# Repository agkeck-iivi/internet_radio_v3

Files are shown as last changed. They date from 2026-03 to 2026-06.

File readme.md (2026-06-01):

# Internet radio v3

# this archive is now historical.  Active development is moved to https://codeberg.org/agkeck/internet_radio_v3

## hardware

* ESP32s3 DevkitC N8R8
* [adafruit pcm5122 audio board](https://learn.adafruit.com/adafruit-pcm5122-i2s-dac/)
*

### prototype

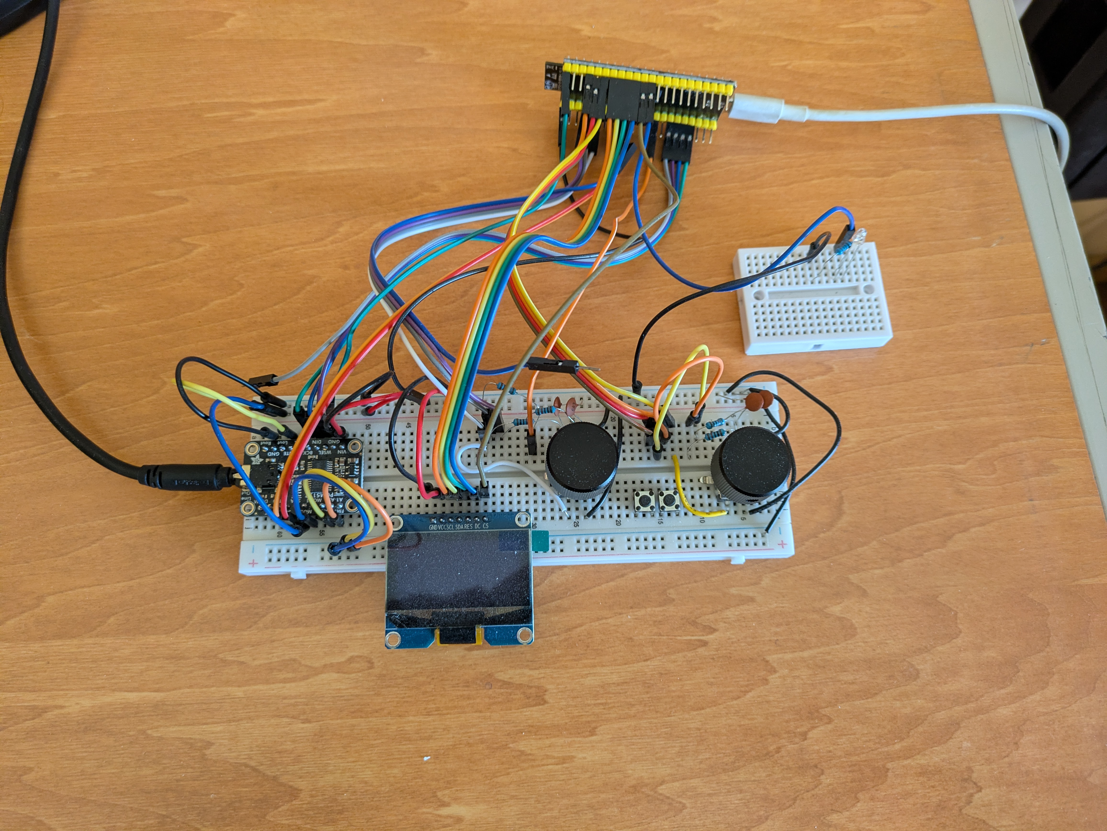
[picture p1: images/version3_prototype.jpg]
Version 3 Prototype


### schematic

Version 3 Schematic

### build

**Version 1**
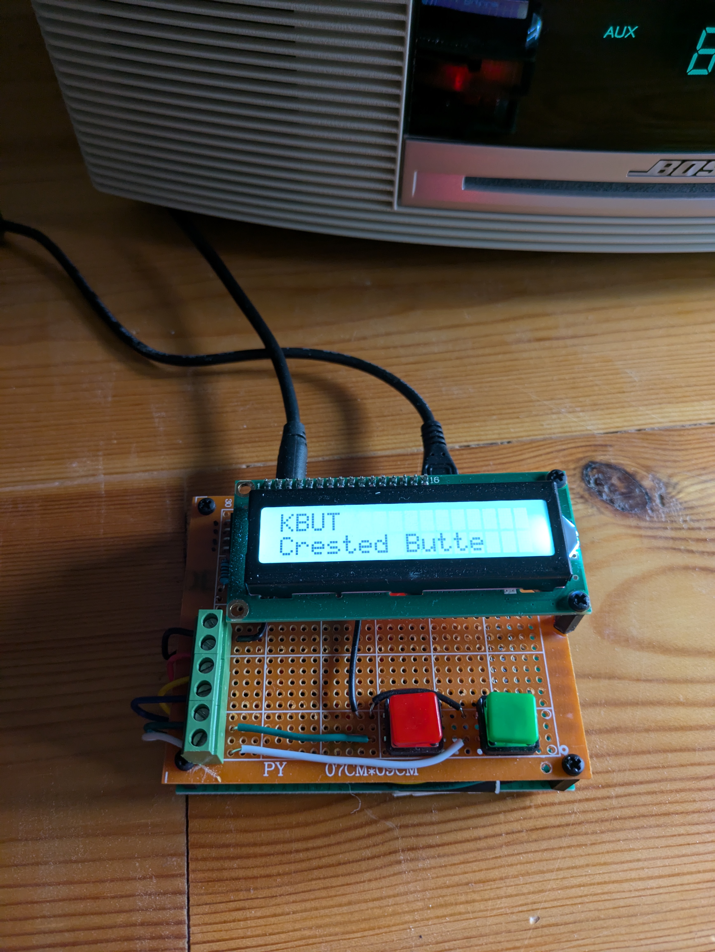
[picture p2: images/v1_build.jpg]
Version 1 Build


**Version 2**
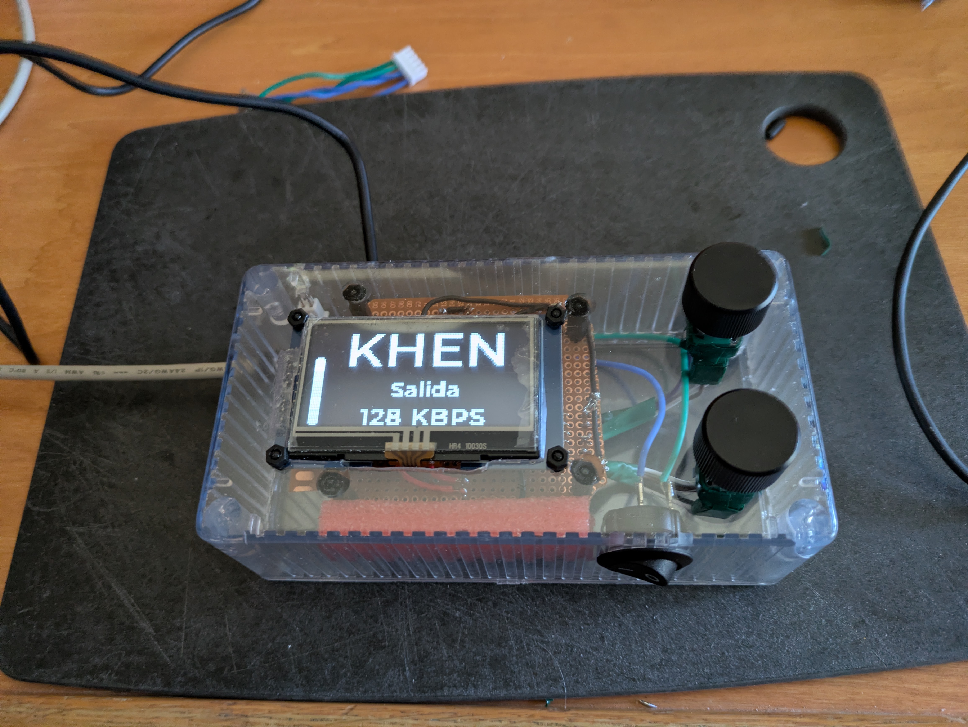
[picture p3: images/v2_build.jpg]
Version 2 Build


**Version 3**
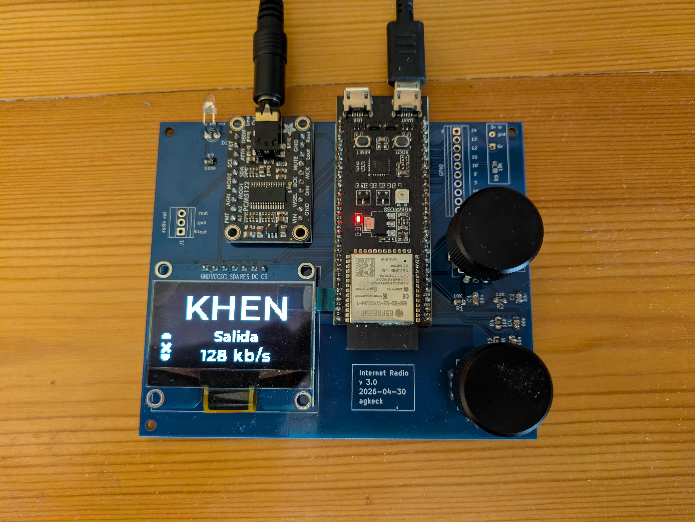
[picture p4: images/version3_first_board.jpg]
Version 3 Build


## software

### version 3 software highlights

Version 3 represents a significant refinement in performance, power management, and hardware integration. Key changes include:

* **Audio Hardware Migration**: Moved from the ES8388 codec to the high-performance **PCM5122 DAC**. This included implementing logarithmic volume scaling for a natural listening experience and custom digital ramp rates for glitch-free transitions.
* **Boot Speed Optimization (Fast Connect)**: Cold boot time was reduced from ~21 seconds to **~6 seconds** by implementing WiFi state persistence in NVS. The system now caches BSSID, channel, IP, and DNS settings to bypass discovery and DHCP phases.
* **Advanced Power Management**: Introduced a configurable power-saving strategy supporting **Light Sleep** and **Deep Sleep** transitions. This includes robust watchdog protection to prevent system hangs during sleep-state changes.
* **Dedicated IR Component**: Extracted Bose IR protocol logic into a reusable `ir_remote` component. The system now automatically synchronizes external audio power states during the device's boot and sleep cycles.
* **UI & Observability**: Refined the LVGL interface with a queue-based thread-safety pattern, real-time throughput tracking (kb/s), and custom graphical indicators (e.g., specialized mute glyphs).
* **Web Configuration**: Introduced a web interface for managing device settings (Analog/Digital attenuation, Power Save modes) with immediate runtime application.
* **NVS Configuration Persistence**: All application settings are now persisted to NVS using individual keys, ensuring backward compatibility and state retention across reboots.
* **Stability & Cleanup**: Factored all hardware assignments into a central GPIO header, implemented spurious encoder signal blanking on wakeup, and aligned the project with **ESP-IDF v5.4.3**.

### audio pipeline

The audio pipeline is virtually the same as in version 1.  We added an accumulator to count the bytes read from the http stream and a periodic task to calculate/update the bitrate display on the screen.  This task calculates a 10 second weighted average of one second bitrates.  When this weighted average is 0 we know that we have not received data for 10 seconds.  We use this signal along with a delay of 15 seconds to determine if we need to reboot the device.  If we have not received data for 10 seconds and we are at least 15 seconds since last boot we reboot the device.

### audio board

In Version 3, the radio migrated from the ES8388 (legacy LyraT design) to the high-performance **PCM5122 DAC** (Adafruit board).

The PCM5122 integration features:

* **Custom Driver**: A dedicated driver implementation that adheres to ESP-ADF conventions while providing low-level register control.
* **Analog Gain Control**: To manage the high output levels of the PCM5122, we implemented a 6 dB reduction in the analog gain stage (Page 1, Register 2).
* **Logarithmic Volume Scaling**: Volume settings (0-100) are mapped logarithmically to the DAC's digital volume registers to provide a natural, linear-sounding response to the user.
* **Attenuation Considerations**: Despite the 6 dB analog reduction, the output remains quite loud. Further digital or analog attenuation may be required in future revisions to better align the volume range with typical AUX-input sensitivities.

### encoders

The hardware pulse counters track the position of the encoders. This device has interupts for pulse thresholds but not for changes in pulse counts.  We use a polling task to check the pulse counts and update the encoder position.  For the volume encoder we clamp the value to the range [0, 100] and arrange the relationship between the pulse count and the [0, 100] range to saturate at the endpoints.  In this way, even if the user turns well past an endpoint the reverse movement will immediately affect the value.

### lvgl

LVGL is used for the display interface. Since LVGL is not thread-safe, we implement a **Queue-based Producer/Consumer pattern** to manage all UI updates safely.

#### Thread Safety & Queue

* **Producer**: Any task (e.g., Wi-Fi events, Encoder Logic) that wants to update the UI creates a `ui_update_message_t` struct. This struct contains an event `type` (enum) and optional `data` (int or string pointer). This message is sent to `g_ui_queue`.
* **Consumer**: The `process_ui_updates()` function runs in the main loop (or a dedicated UI task). It consumes messages from `g_ui_queue` and performs the actual LVGL API calls (e.g., `lv_label_set_text`, `lv_screen_load`). This ensures all LVGL operations happen in a single context.

#### Screens

The application uses three primary screens:

1. **Home Screen**: The main dashboard showing the Volume Slider, Station Call Sign, Origin, and Bitrate.
2. **Station Selection**: Displays a "Roller" widget allowing the user to scroll through the list of stations.
3. **Message Screen**: A generic, reusable screen with a centered label used for notifications (e.g., "Rebooting", "Provisioning", "IP Address").

#### Messaging

To display a message on the **Message Screen**:

1. **Fixed Messages**: Helper functions like `switch_to_reboot_screen()` send a message type (e.g., `SWITCH_TO_REBOOT_SCREEN`) that triggers the consumer to load the Message Screen and set a hardcoded string (e.g., "Rebooting").
2. **Arbitrary Messages**: To display dynamic text (like an IP address), the system uses the `UPDATE_IP_LABEL` message type.
    * The producer sends a message with `type = UPDATE_IP_LABEL` and `data.str_value = "My String"`.
    * The consumer reads specific string pointer and updates the label on the Message Screen.
    * *Note: Ensure the string pointer remains valid until processed, or use static/global buffers.*

### wifi

The device relies on Wi-Fi for internet connectivity. If no Wi-Fi credentials are provided (e.g., typically on the first boot), the device enters **Provisioning Mode**.

**Provisioning Mode**:

* The device broadcasts a Bluetooth LE (BLE) service.
* Use the **Espressif BLE Provisioning** app (available on iOS and Android) to connect to the device.
* Follow the app instructions to scan for Wi-Fi networks and provide the SSID and password.
* Once credentials are received, the device will connect to the Wi-Fi network and save the credentials to NVS for future boots.
* **Forced Reprovisioning**: To reset the Wi-Fi credentials and force the device back into provisioning mode, **press and hold the Volume Encoder button** while powering on (or rebooting) the device.

### ir

The Bose Wave radio uses an IR remote control for all functions. Version 2 is designed for this particular unit so we generate our own IR signals to control the radio.  After sniffing the IR signals with ir_nec_transciever project we see that the radio does not use the NEC protocal.  Using 10 samples of the on/off button and 10 samples of the aux button we create a concensus signal for each message. The colab: `bose_sig_analysis.ipynb` shows the analysis of the IR signals.

The bose IR protocal is stateful: the on/off button performs different functions based on the state of the radio.  The aux button is stateless, this signal will always result in the radio being on with input from the aux jack.  Therefore we use aux as the on signal and aux + on/off as the off signal.  We send aux during the boot sequence to ensure that the radio is on when we boot.  We expect the user to double click the volume encoder to turn the radio off.

### nvs

The system uses Non-Volatile Storage (NVS) to persist all critical states and settings:

* **Application Settings**: Analog and Digital attenuation, Power Save mode, sleep delays, and IR transmitter status.
* **Device State**: Current volume level, mute status, and the last selected station index.
* **WiFi State**: Cached BSSID, channel, and IP configuration for "Fast Connect" boot optimizations.

Settings are stored under the `app_config` namespace using individual keys for robust schema evolution.

### application configuration

The radio provides a web interface and a JSON API for real-time configuration. Access the interface at `http://<ESP32_IP_ADDRESS>/config`.

#### Configuration Parameters

| Parameter | Key | Values | Description |
| :--- | :--- | :--- | :--- |
| **Analog Attenuation** | `analog_attenuation` | `0` (0dB), `1` (-6dB) | Hardware gain stage control. |
| **Digital Attenuation** | `digital_attenuation` | `0, 6, 12, ..., 48` | Digital signal scaling after hardware gain. |
| **Power Save Mode** | `power_save_mode` | `0` (None), `1` (Light), `2` (Deep) | Sleep strategy selection. |
| **Light Sleep Delay** | `light_sleep_delay_ms` | Milliseconds | Timeout to enter Light Sleep. |
| **Deep Sleep Delay** | `deep_sleep_delay_ms` | Milliseconds | Additional timeout to move from Light to Deep Sleep. |
| **IR Remote Control** | `ir_protocol` | `0` (None), `1` (Bose Wave), `2` (Dubas Radio) | IR remote protocol selection. |

#### API Access

* **GET `/api/config`**: Returns the current application configuration.
* **POST `/api/config`**: Updates the configuration immediately. Changes are persisted to NVS.

Example update with all parameters:

```bash
curl -X POST -H "Content-Type: application/json" \
     -d '{
       "analog_attenuation": 1,
       "digital_attenuation": 12,
       "power_save_mode": 2,
       "light_sleep_delay_ms": 30000,
       "deep_sleep_delay_ms": 60000,
       "ir_protocol": 1
     }' \
     http://<ESP32_IP_ADDRESS>/api/config
```

Initial station data is stored in a constant array.  On first boot, if the spiffs is not initialized we create a default station json file based on the constant array.  Thereafter, on boot the spiffs should be found and the json file serves as the source of truth for station data.  We provide an API to load the station data from the json file and save the station data to the json file.

To download the current stations:

```bash
curl http://<ESP32_IP_ADDRESS>/api/stations -o stations.json
```

To update the stations:

```bash
curl -X POST -H "Content-Type: application/json" -d @stations.json http://<ESP32_IP_ADDRESS>/api/stations
```

where the codec enum uses these values:

0: MP3
1: AAC
2: OGG
3: FLAC

For help finding stream URIs and codecs for your favorite stations, see the [Station Discovery Guide](station_discovery.md).

### web update to station data

We provide a web interface to update the station data at <ESP32_IP_ADDRESS>/api/stations (or just <ESP_IP_ADDRESS> where there is a link to station data.)  From the web interface we can add, remove, and update station data as well a reorder the list of stations.  The station data is saved to the spiffs and a reboot will apply the changes.

## power management

The radio implements a multi-stage power-saving strategy to minimize energy consumption when idle.

*Note: In local tests setting the router's default dns server to 8.8.8.8  (google dns) or 1.1.1.1 (cloudflare dns) results in faster wakeup times.*

### Power Requirements Table

The following table outlines the current draw and estimated annual energy costs for each operational state. Estimates assume 24/7 operation in the specified state and an electricity cost of **$0.15 per kWh**.

| State | Current (mA) | Power (W) | Annual Energy (kWh) | Annual Cost ($)* |
| :--- | :--- | :--- | :--- | :--- |
| **None (Active)** | 190 | 0.95 | 8.32 | $1.25 |
| **Light Sleep** | 18 | 0.09 | 0.79 | $0.12 |
| **Deep Sleep** | ~8 (est.)† | 0.04 | 0.35 | $0.05 |

*\*Costs are rounded to the nearest cent.*
*†Deep sleep current is dominated by the DevKitC's onboard LDO quiescent current (~5mA) and Power LED (~3mA), as the ESP32-S3 chip itself draws <100µA in this state.*

#### Sleep States

* **Light Sleep**: Entered after a period of inactivity while muted. The CPU state is preserved, and the **SSD1306 screen is automatically powered off** to save energy. The system can be woken by either encoder button.
* **Deep Sleep**: Entered after an extended period in light sleep (if configured). The system performs a full power-down. **Only the Station button (GPIO 6)** can wake the device from this state.
* **IR Sync**: If enabled, the system automatically sends a "Power Off" IR command to the Bose radio when entering sleep, and a "Power On" command when waking.

## operation

The radio's user interface is driven by two rotary encoders, each equipped with an integrated push button (switch).

### Control Summary Table

| Control | Action | Function |
| :--- | :--- | :--- |
| **Volume Encoder** | Rotation | Adjust volume (0-100); Auto-unmutes if turned |
| | Single Click | Toggle Mute/Unmute; **Wake from Light Sleep** |
| | Double Click | Send **Bose ON/OFF** IR command |
| | **Hold at Boot** | **Force Reprovisioning** (Wipe Wi-Fi credentials) |
| **Station Encoder** | Rotation | Scroll through stations; Selects after 2s inactivity |
| | Short Press | Display **IP Address** (3s); **Wake from Mute/Sleep** |
| | Long Press (>1.5s) | **Reboot** device |

---

### Detailed Usage

#### Volume Encoder (Left)

* **Rotation**: Sets the volume level between 0 and 100.
  * The volume is saved to NVS and persists across reboots.
  * If the device is muted, any rotation will automatically restore the previous volume plus or minus the rotation delta.
* **Single Click**: Toggles the mute state.
  * **Wakeup**: If the device is in **Light Sleep**, clicking this button will wake the system and automatically unmute the audio.
* **Double Click**: Triggers the IR transmitter to send a power toggle command to the connected Bose system.
* **Boot Action**: Holding this button during power-on or reset will trigger `wifi_prov_mgr_reset_provisioning()`, allowing you to connect a new Wi-Fi network via BLE.

#### Station Encoder (Right)

* **Rotation**: Navigates the station list.
  * Turning the knob switches the display to the **Station Selection** screen.
  * **Auto-Selection**: Once you stop turning, the radio waits for **2 seconds** before committing the change, switching the stream, and returning to the Home screen.
* **Short Press**:
  * **Normal Mode**: Briefly switches the screen to show the current IP address.
  * **Mute/Sleep Mode**: If the device is muted or in **Light Sleep**, this button acts as a "Wake" key, restoring the audio immediately.
  * **Deep Sleep Wakeup**: This is the **primary wakeup button** for Deep Sleep. Because GPIO 6 is an RTC-capable pin, it is used to bring the system back from a deep sleep state (performing a full reboot).
* **Long Press**: Holding for more than 1.5 seconds triggers an immediate system reboot.

## Bugs

* Between the prototype and the first board we moved the volume button to gpio 42 to facilitate traces on the PCB.  Unfortunately we forgot that gpio 42 is not an RTC GPIO pin.  As a result, the volume button cannot wake the device from deep sleep.  We moved the wakeup function to the station button (gpio 6) and that works fine.  Currently volume turns it off and station turns it on.  We'll see how that works for us.

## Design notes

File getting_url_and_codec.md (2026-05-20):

# How to find url/codec for  radio streams, current song, and bitrate

## Identifying url

<https://fmstream.org> or ask gemini

## Identifying codec

```{bash}
ffprobe -v error -select_streams a:0 -show_entries stream=codec_name -of default=noprint_wrappers=1:nokey=1 <url>
```

## Measuring bitrate

```{bash}
ffprobe -v error -select_streams a:0 -show_entries stream=bit_rate -of default=noprint_wrappers=1:nokey=1 <url>
```

## getting currently playing song

### kexp

```{bash}
curl -s "https://api.kexp.org/v2/plays/?limit=1" | jq '.results[0] | {artist, song, album}'
```

## Station Bitrate Reference

The following table shows the measured bitrates for the default radio stations (calculated using `ffprobe`).

| Call Sign | Measured Bitrate | Sampling Frequency | URI |
| :--- | :--- | :--- | :--- |
| KEXP | 160 kbps | 44100 Hz | `https://kexp.streamguys1.com/kexp160.aac` |
| KBUT | 64 kbps | 22050 Hz | `http://playerservices.streamtheworld.com/api/livestream-redirect/KBUTFM.mp3` |
| KSUT | 64 kbps | 48000 Hz | `https://ksut.streamguys1.com/kute` |
| KDUR | 128 kbps | 44100 Hz | `https://kdurradio.fortlewis.edu/stream` |
| KOTO | 128 kbps | 44100 Hz | `http://playerservices.streamtheworld.com/api/livestream-redirect/KOTOFM.mp3` |
| KHEN | 128 kbps | 44100 Hz | `https://stream.pacificaservice.org:9000/khen_128` |
| KWSB | 128 kbps | 44100 Hz | `https://kwsb.streamguys1.com/live` |
| KFFP | 256 kbps | 44100 Hz | `http://listen.freeformportland.org:8000/stream` |
| KBOO | 192 kbps | 48000 Hz | `https://live.kboo.fm:8443/high` |
| KXLU | 48 kbps | 44100 Hz | `http://kxlu.streamguys1.com:80/kxlu-lo` |
| WPRB | 96 kbps | 44100 Hz | `https://wprb.streamguys1.com/listen.mp3` |
| WMBR | 128 kbps | 44100 Hz | `https://wmbr.org:8002/hi` |
| KALX | 128 kbps | 48000 Hz | `https://stream.kalx.berkeley.edu:8443/kalx-128.mp3` |
| WFUV | 128 kbps | 44100 Hz | `https://onair.wfuv.org/onair-hi` |
| KUFM | 64 kbps | 22050 Hz | `https://playerservices.streamtheworld.com/api/livestream-redirect/KUFMFM.mp3` |
| KRCL | 192 kbps | 44100 Hz | `https://stream.xmission.com/krcl-high` |

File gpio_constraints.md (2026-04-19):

# GPIO Constraints for ESP32-S3 N16R8 (Octal SPI)

This document outlines the GPIO pins on the ESP32-S3 N16R8 DevKitC that are either reserved, have special functions, or should be used with caution to avoid system instability.

## 1. Reserved for Internal Memory (Octal SPI)
The **N16R8** variant uses **Octal SPI** for both its 16MB Flash and 8MB PSRAM. This consumes a significant number of GPIOs that are typically available on standard Quad SPI modules.

> [!CAUTION]
> **DO NOT USE** the following pins. Using them will interfere with memory access and cause the system to crash or fail to boot.

| GPIO | Function |
| :--- | :--- |
| **26** | SPICU / PSRAM D4 |
| **27** | SPICD / PSRAM D5 |
| **28** | SPIWP / PSRAM D6 |
| **29** | SPIHD / PSRAM D7 |
| **30** | SPIIO4 / PSRAM D0 |
| **31** | SPIIO5 / PSRAM D1 |
| **32** | SPIIO6 / PSRAM D2 |
| **33** | SPIIO7 / PSRAM D3 |
| **34** | SPICS1 / PSRAM CS |
| **35** | SPICLK / Flash CLK |
| **36** | SPICS0 / Flash CS |
| **37** | SPIDQS / Memory DQS |

---

## 2. On-Board Hardware
The DevKitC has specific pins hard-wired to peripheral components.

| GPIO | Component | Note |
| :--- | :--- | :--- |
| **48** | **RGB LED** | Connected to the WS2812 RGB LED. Toggling this pin will change the LED color. |
| **43** | **UART0 TX** | Connected to the USB-to-UART bridge (TX). |
| **44** | **UART0 RX** | Connected to the USB-to-UART bridge (RX). |
| **19** | **USB D-** | Native USB D- line. |
| **20** | **USB D+** | Native USB D+ line. |

---

## 3. Strapping Pins
These pins are sampled during the boot process to determine the boot mode or voltage levels. While they can be used as general-purpose I/O after boot, they must not be held in the "wrong" state during power-on.

| GPIO | Name | Default | Impact |
| :--- | :--- | :--- | :--- |
| **0** | GPIO0 | Pull-up | Low at boot enters Download Mode. |
| **45** | VDD_SPI | Pull-down | **CRITICAL:** Sets Flash/PSRAM voltage. Leave floating or low. |
| **46** | GPIO46 | Pull-down | Must be Low at boot for normal operation. |

---

## 4. Hardware Debugging (JTAG)
These pins are used for on-chip debugging. If you are not using an external JTAG debugger, these can be used for other purposes.

| GPIO | JTAG Function |
| :--- | :--- |
| **39** | MTCK |
| **40** | MTDO |
| **41** | MTDI |
| **42** | MTMS |

---

## 5. ADC2 Constraints (Wi-Fi Conflict)
GPIOs **11 through 20** are connected to ADC2. On the ESP32-S3, ADC2 cannot be used for analog readings while the Wi-Fi or Bluetooth drivers are active.

> [!TIP]
> Use ADC1 pins (GPIO 1-10) for analog sensors if Wi-Fi is enabled.

---

## Summary of Safe Pins
For high-speed signals like I2S or SPI, the following pins are generally "safe" and unencumbered on the S3-N16R8:
*   **GPIO 1 - 10** (ADC1, free for all uses)
*   **GPIO 15 - 18** (If not using specific peripherals)
*   **GPIO 21**
*   **GPIO 38**
*   **GPIO 47**

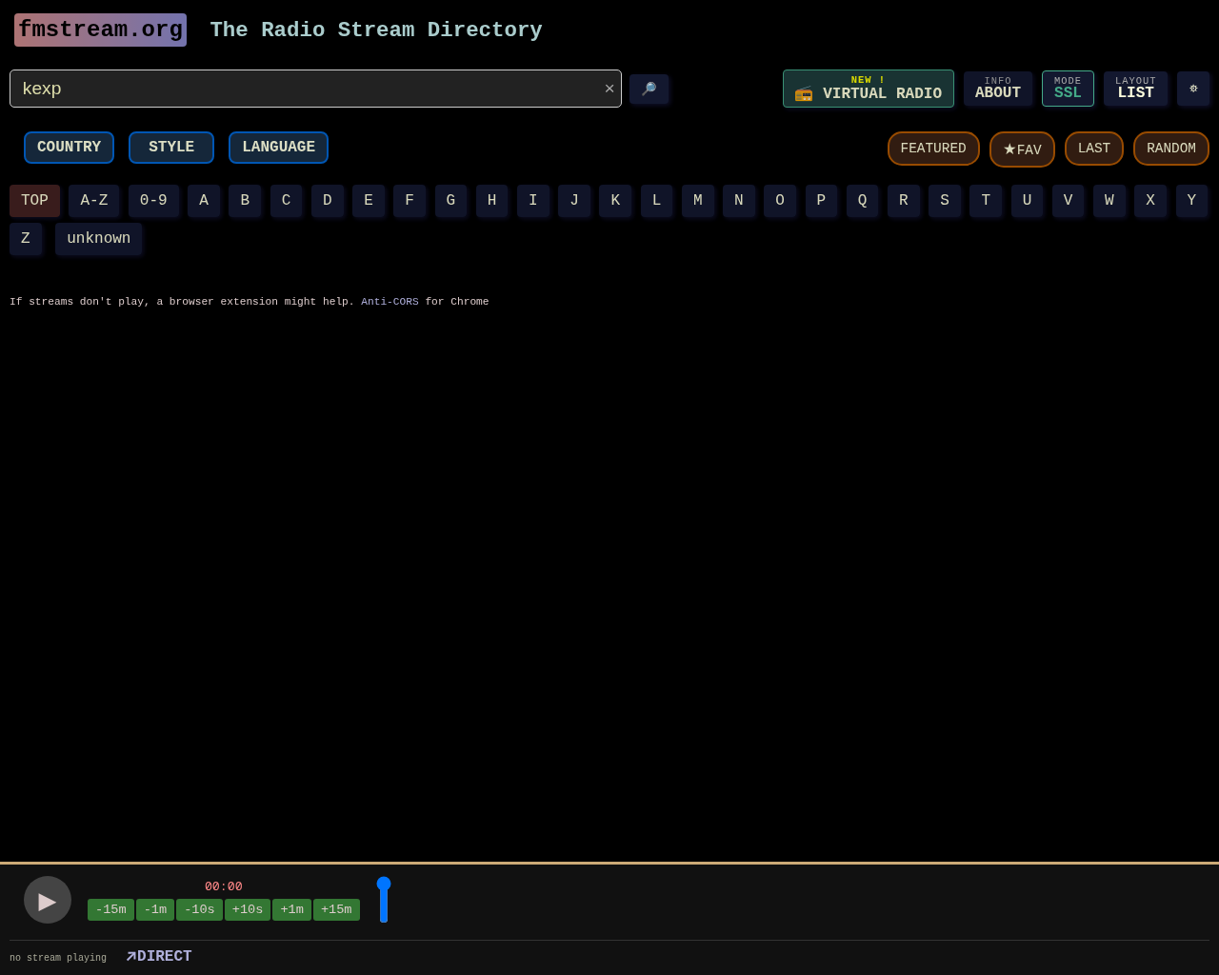
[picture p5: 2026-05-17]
images/fmstream_kexp.png

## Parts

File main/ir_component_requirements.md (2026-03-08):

# introduction
The internet radio uses ir remote control to control the on/off state of the audio device to which it is connected.  During boot time the audio device is turned on.  One can also toggle the on/off state of the audio device by a double click on the volume button.  This code is entwined with the main logic of the application and should be extracted into a separate component.

# goal
Extract the the ir remote implementation into a component.  This component should export an abstract interface and should be designed to allow other ir remote protocols to be added easily.

# requirements
    * separate component for ir remote implementation
    * export functions to init, deinit, turn_audio_on, turn_audio_off, toggle_audio, enable_ir_remote, disable_ir_remote
    * use enum to identify the ir remote protocol
    * update main application to use this new component
    * make it possible to easily remove ir remote functionality entirely

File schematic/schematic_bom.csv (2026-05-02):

Reference | Qty | Value | DNP | Exclude from BOM | Exclude from Board | Footprint | Datasheet
C1,C2,C3,C4 | 4 | 68nF |  |  |  | Capacitor_SMD:C_0805_2012Metric_Pad1.18x1.45mm_HandSolder | ~
D1 | 1 | LED |  |  |  | LED_THT:LED_D3.0mm_IRGrey | ~
J1 | 1 | Audio Out |  |  |  | TerminalBlock:TerminalBlock_Xinya_XY308-2.54-3P_1x03_P2.54mm_Horizontal | ~
J2 | 1 | GPIO |  |  |  | TerminalBlock:TerminalBlock_Xinya_XY308-2.54-10P_1x10_P2.54mm_Horizontal | ~
J3 | 1 | Conn_01x02 |  |  |  | Connector_Wire:SolderWire-0.1sqmm_1x02_P3.6mm_D0.4mm_OD1mm | ~
oled128x1 | 1 | ~ |  |  |  | oled128x64_spi:oled128x64_spi
R1,R2,R3,R4 | 4 | 10k |  |  |  | Resistor_SMD:R_0805_2012Metric_Pad1.20x1.40mm_HandSolder | ~
R6 | 1 | 10K |  |  |  | Resistor_SMD:R_0805_2012Metric_Pad1.20x1.40mm_HandSolder | ~
R7 | 1 | 100R |  |  |  | Resistor_SMD:R_0805_2012Metric_Pad1.20x1.40mm_HandSolder | ~
S1,S2 | 2 | PEC11R-4220F-S0024 |  |  |  | rotary_encoder:XDCR_PEC11R-4220F-S0024
U1 | 1 | ESP32-S3-DevKitC |  |  |  | PCM_Espressif:ESP32-S3-DevKitC
U2 | 1 | pcm5122module |  |  |  | audio_boards:pcm5122_module

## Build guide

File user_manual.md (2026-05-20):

# Internet Radio User Manual

Welcome to your new Internet Radio! This manual will guide you through the initial setup, daily operation, and advanced configuration of your device.

## Note: Converting user manual markdown to pdf

```bash
pandoc user_manual.md -o user_manual.pdf --pdf-engine=typst -V mainfont="Libertinus Serif"
```

## 1. Initial Setup and Wi-Fi Provisioning

When you first power on the radio, it will not know how to connect to your local Wi-Fi network. It will enter "Provisioning Mode" to allow you to securely provide these credentials.

### What You Will See

The radio's display will show a message indicating it is waiting to be provisioned. To connect it to your network, you will need to use a smartphone application provided by Espressif.

### Step-by-Step Provisioning Guide

1. **Download the App**: Download the **ESP BLE Provisioning** app from the Apple App Store or Google Play Store.
2. **Start Provisioning**: Open the app and tap **"Provision Device"**.
3. **Bypass QR Code**:  This device does not use a QR code for pairing.  Instead, the device will broadcast its name (agk radio) and MAC address via Bluetooth Low Energy (BLE).  Select the agk radio:<mac-address> from the list of discovered devices.
4. **Scan for Wi-Fi**: Once connected via Bluetooth, the app will scan for available Wi-Fi networks in your area.
5. **Enter Credentials**: Select your Wi-Fi network (2.4GHz) from the list and enter your Wi-Fi password.
6. **Complete Setup**: The app will send the credentials to the radio. The app will display "Provisioning Successful," and the radio will connect to the internet.
7. **Ready to Play**: The radio's screen will briefly display its newly acquired IP address and then begin playing the default internet radio stream.

*Note: If you ever change your Wi-Fi router or password, you can force the radio back into this Provisioning Mode by pressing and holding the Volume knob while powering on or resetting the device.*

## 2. Operating the Radio

The radio is controlled entirely using two rotary knobs. Both knobs can be turned and pushed in like a button.

### Volume Control

* **Turn**: Adjusts the volume from 0 to 100. If the radio is currently muted, turning the knob will automatically unmute the audio and adjust the volume.
* **Single Click**: Toggles the audio mute on and off. If the radio has entered its "Light Sleep" power-saving mode (where the screen turns off), a single click will wake it up and unmute the audio.
* **Double Click**: If you are using the radio an Infrared (IR) signal to toggle the power on an attached receiver if configured to do so.
* **Hold at Boot**: As mentioned above, holding this button while the radio powers on will erase saved Wi-Fi credentials and start Provisioning Mode.

### Station Selection

* **Turn**: Scrolls through your list of saved radio stations. The screen will switch to a "Roller" view. Once you find the station you want, simply stop turning. After 2 seconds of inactivity, the radio will automatically select the new station and begin playing.
* **Short Press**:
  * Displays the radio's current **IP Address** on the screen for 3 seconds. You will need this address to access the web configuration.
  * If the radio is muted or sleeping, a short press acts as a **"Wake"** button to restore audio and power on the screen. This button is also capable of waking the radio from "Deep Sleep."
* **Long Press**: Holding this button for more than 1.5 seconds will reboot the radio.

### Power Management

To save energy, the radio can automatically enter sleep states if it is muted and left inactive. The behavior depends on your configured Power Save Mode:

* **None**: No power savings. The radio remains fully active (~190mA, costing ~$1.25/year).
* **Light Sleep Only**: After a period of inactivity, the screen turns off to save power, but the radio remains connected to Wi-Fi. Pressing either knob will wake it up (~18mA, costing ~$0.12/year).
* **Light -> Deep Sleep**: After an extended period in Light Sleep, the radio powers down almost completely. Pressing the Station knob will wake the device and perform a fresh boot (~8mA, costing ~$0.05/year).

## 3. Web Interface Configuration

You can configure advanced settings and manage your saved radio stations using the built-in web interface.

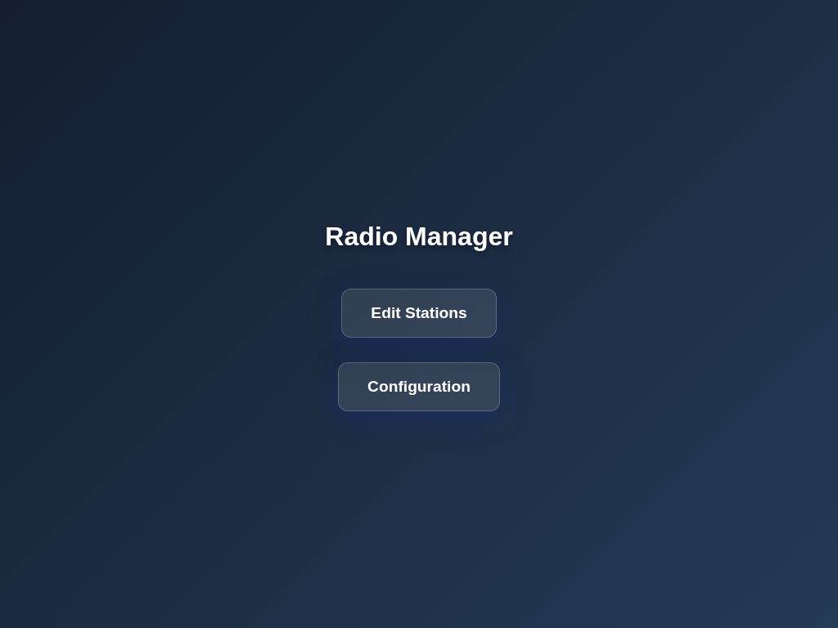
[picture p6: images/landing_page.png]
Landing Page


To access the interface, find the radio's IP address (by short-pressing the Station knob) and type it into the web browser of a computer or smartphone connected to the same Wi-Fi network. For example: `http://192.168.1.100`

### Device Configuration

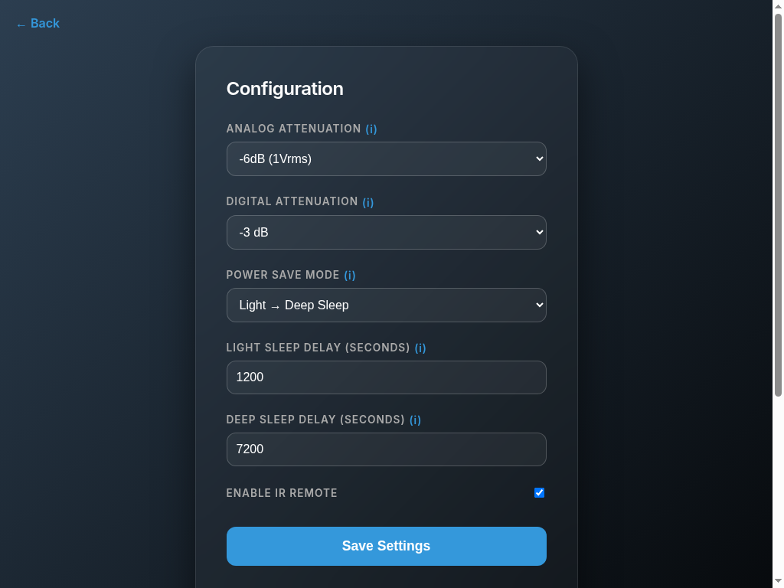
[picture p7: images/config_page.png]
Device Configuration


Navigate to the device configuration page (e.g., `http://<IP_ADDRESS>/config`) to adjust system settings:

* **Analog/Digital Attenuation**: These settings allow you to fine-tune the audio output levels to balance the gain of your external speakers or amplifier with the output of the internet radio. It is highly recommended to use **Analog Attenuation** first, as this preserves the full bit depth (and therefore the quality) of the audio signal. If the output is still too loud after applying analog attenuation, you can apply additional reduction using **Digital Attenuation**.
* **Power Save Mode**: Choose your preferred power savings strategy: **None** (always on), **Light Sleep Only** (turns off screen), or **Light -> Deep Sleep** (turns off screen, then fully powers down).
* **Sleep Delays**: Configure exactly how many seconds the radio should wait while muted before entering Light Sleep, and how long it should wait in Light Sleep before entering Deep Sleep.
* **IR Remote**: Enable or disable the IR transmitter used to control external Bose systems.

### Station Configuration

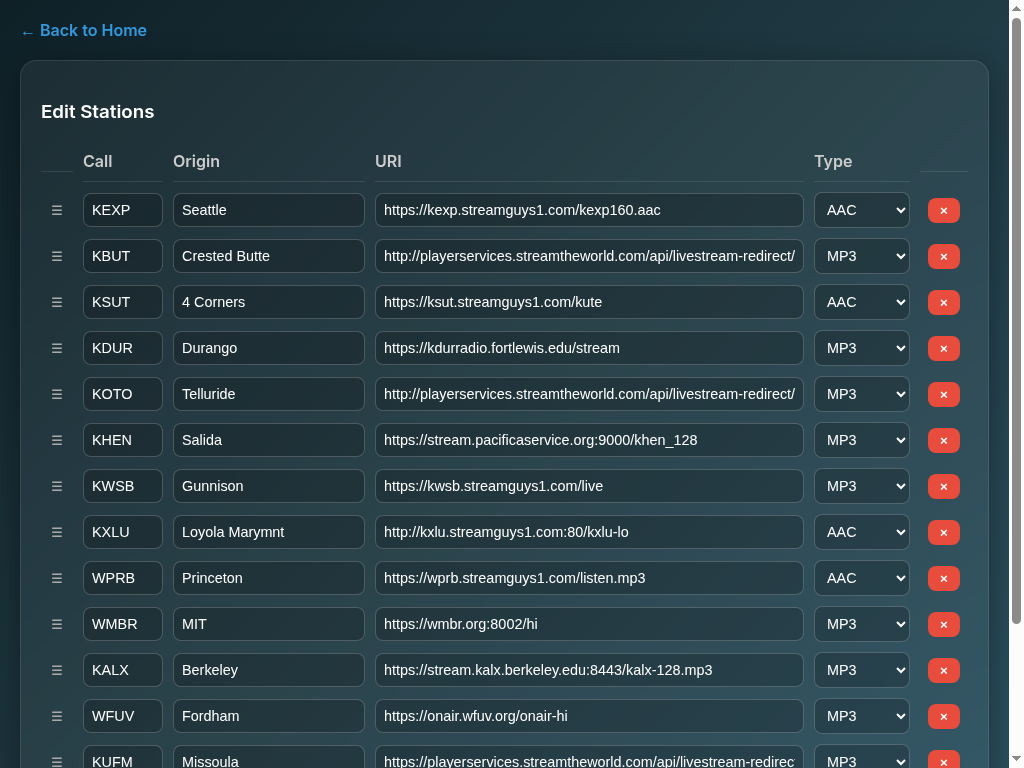
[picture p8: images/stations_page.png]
Station Configuration


Navigate to the station configuration page to manage your radio dial. From this page you can:

* **Add New Stations**: Enter the Name, Stream URI, and select the appropriate audio codec (MP3, AAC, OGG, or FLAC).
* **Edit/Remove Stations**: Update existing stream URLs if they change, or delete stations you no longer listen to using the "**x**" button.
* **Reorder**: Change the order in which stations appear when you turn the Station knob by **dragging** the rows up or down.

Changes made on the station configuration page are saved permanently, but the radio may need to be rebooted to apply the new list to the main interface.

## 4. Finding Radio Streams

If you want to add a new station, you will need its direct audio stream URL. Standard website URLs (like `npr.org`) will not work directly.

The easiest way to find compatible stream URLs is to use **[fmstream.org](https://fmstream.org)**.

1. Search for your desired radio station on the site (for example, "KEXP").
1. Set layout to *FULL*.
2. Look for the direct streaming links provided in the search results. Next to each URL, you will see the **format/codec** (e.g., MP3, AAC) and the bitrate (e.g., 128 kbps).
3. Copy the URL that corresponds to the format you want (typically ending in `.mp3` or `.aac`), and paste it into your radio's Station Configuration page.

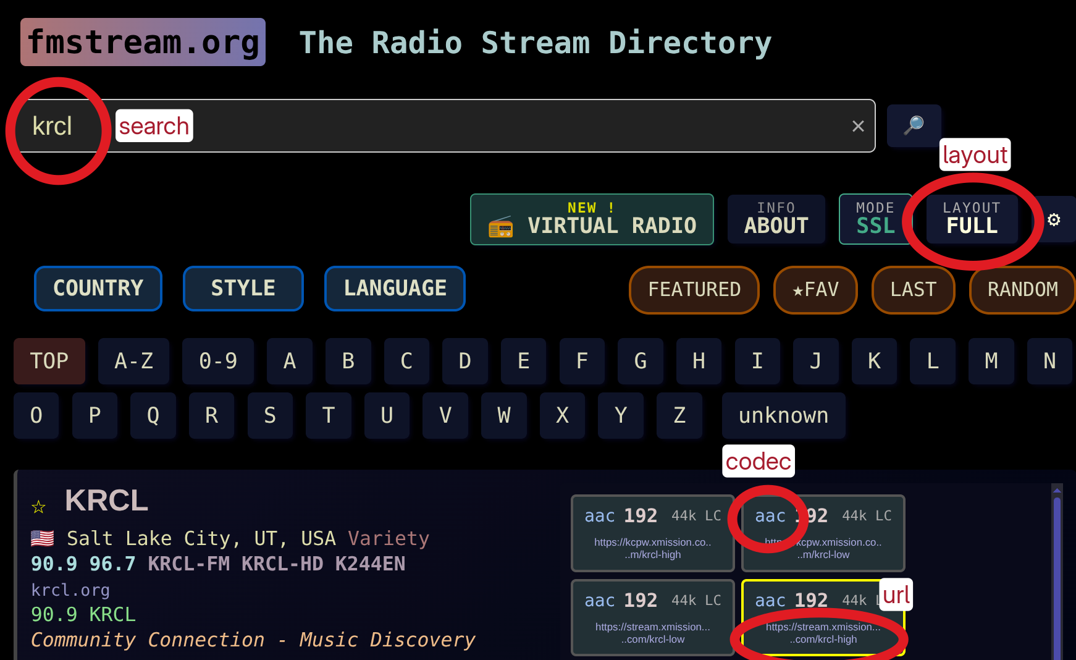
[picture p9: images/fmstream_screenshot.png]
fmstream KEXP Example


1. In the radio's configuration, select the exact codec (MP3, AAC, etc.) that was listed next to the URL on the fmstream website.
2. Use *origin* to help describe the station.  You have about 14 characters available on the display.

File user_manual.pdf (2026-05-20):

## Internet Radio User Manual

Welcome to your new Internet Radio! This manual will guide you through the initial setup, daily operation, and advanced configuration of your device.

### Note: Converting user manual markdown to pdf

pandoc user_manual.md -o user_manual.pdf --pdf-engine=typst -V mainfont="Libertinus Serif"

### 1. Initial Setup and Wi-Fi Provisioning

When you first power on the radio, it will not know how to connect to your local Wi-Fi network. It will enter “Provisioning Mode” to allow you to securely provide these credentials.

What You Will See
The radio’s display will show a message indicating it is waiting to be provisioned. To connect it to your network, you will need to use a smartphone application provided by Espressif.

Step-by-Step Provisioning Guide
1. Download the App: Download the ESP BLE Provisioning app from the Apple App Store or Google Play Store.
2. Start Provisioning: Open the app and tap “Provision Device”.
3. Bypass QR Code: This device does not use a QR code for pairing. Instead, the device will broadcast its name (agk radio) and MAC address via Bluetooth Low Energy (BLE). Select the agk radio: from the list of discovered devices.
4. Scan for Wi-Fi: Once connected via Bluetooth, the app will scan for available Wi-Fi networks in your area.
5. Enter Credentials: Select your Wi-Fi network (2.4GHz) from the list and enter your Wi-Fi password.
6. Complete Setup: The app will send the credentials to the radio. The app will display “Provisioning Successful,” and the radio will connect to the internet.
7. Ready to Play: The radio’s screen will briefly display its newly acquired IP address and then begin playing the default internet radio stream.

Note: If you ever change your Wi-Fi router or password, you can force the radio back into this Provisioning Mode by pressing and holding the Volume knob while powering on or resetting the device.

### 2. Operating the Radio

The radio is controlled entirely using two rotary knobs. Both knobs can be turned and pushed in like a button.

Volume Control
- Turn: Adjusts the volume from 0 to 100. If the radio is currently muted, turning the knob will automatically unmute the audio and adjust the volume.

- Single Click: Toggles the audio mute on and off. If the radio has entered its “Light Sleep” power-saving mode (where the screen turns off), a single click will wake it up and unmute the audio.
- Double Click: If you are using the radio an Infrared (IR) signal to toggle the power on an attached receiver if configured to do so.
- Hold at Boot: As mentioned above, holding this button while the radio powers on will erase saved Wi-Fi credentials and start Provisioning Mode.

Station Selection
- Turn: Scrolls through your list of saved radio stations. The screen will switch to a “Roller” view. Once you find the station you want, simply stop turning. After 2 seconds of inactivity, the radio will automatically select the new station and begin playing.
- Short Press:
- Displays the radio’s current IP Address on the screen for 3 seconds. You will need this address to access the web configuration.
- If the radio is muted or sleeping, a short press acts as a “Wake” button to restore audio and power on the screen. This button is also capable of waking the radio from “Deep Sleep.”
- Long Press: Holding this button for more than 1.5 seconds will reboot the radio.

Power Management
To save energy, the radio can automatically enter sleep states if it is muted and left inactive. The behavior depends on your configured Power Save Mode:
- None: No power savings. The radio remains fully active (~190mA, costing ~$1.25/year).
- Light Sleep Only: After a period of inactivity, the screen turns off to save power, but the radio remains connected to Wi-Fi. Pressing either knob will wake it up (~18mA, costing ~$0.12/year).
- Light -> Deep Sleep: After an extended period in Light Sleep, the radio powers down almost completely. Pressing the Station knob will wake the device and perform a fresh boot (~8mA, costing ~$0.05/year).

### 3. Web Interface Configuration

You can configure advanced settings and manage your saved radio stations using the built-in web interface.

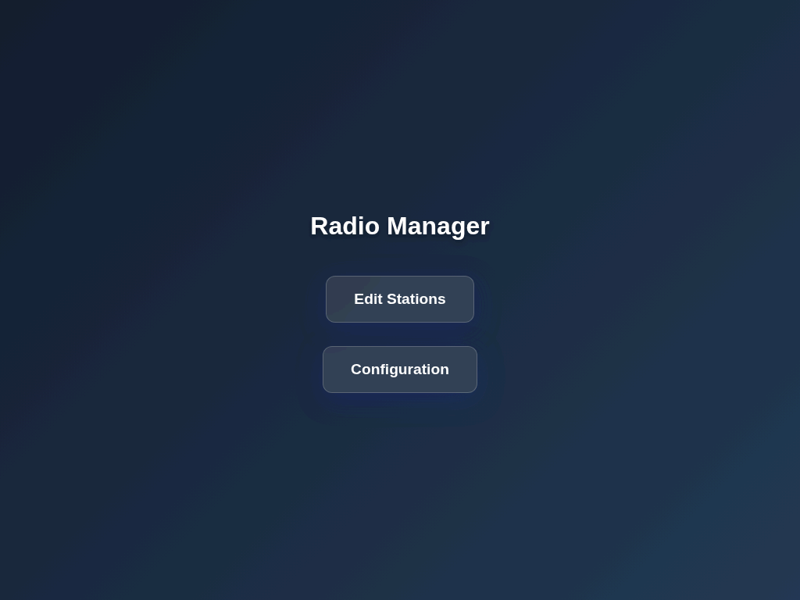
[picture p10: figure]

Figure 1: Landing Page

To access the interface, find the radio’s IP address (by short-pressing the Station knob) and type it into the web browser of a computer or smartphone connected to the same Wi-Fi network. For
example: http://192.168.1.100

Device Configuration

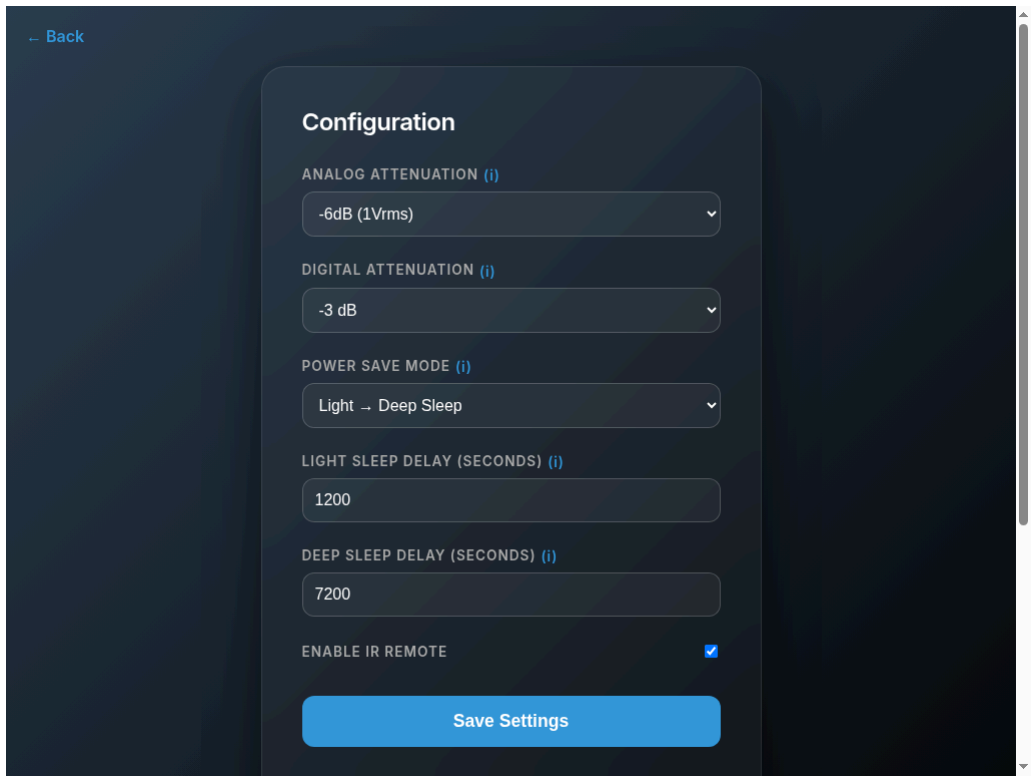
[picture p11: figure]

Figure 2: Device Configuration

Navigate to the device configuration page (e.g., http://<IP_ADDRESS>/config) to adjust system settings:

- Analog/Digital Attenuation: These settings allow you to fine-tune the audio output levels to balance the gain of your external speakers or amplifier with the output of the internet radio. It is highly recommended to use Analog Attenuation first, as this preserves the full bit depth (and therefore the quality) of the audio signal. If the output is still too loud after applying analog attenuation, you can apply additional reduction using Digital Attenuation.
- Power Save Mode: Choose your preferred power savings strategy: None (always on), Light Sleep Only (turns off screen), or Light -> Deep Sleep (turns off screen, then fully powers down).
- Sleep Delays: Configure exactly how many seconds the radio should wait while muted before entering Light Sleep, and how long it should wait in Light Sleep before entering Deep Sleep.
- IR Remote: Enable or disable the IR transmitter used to control external Bose systems.

Station Configuration

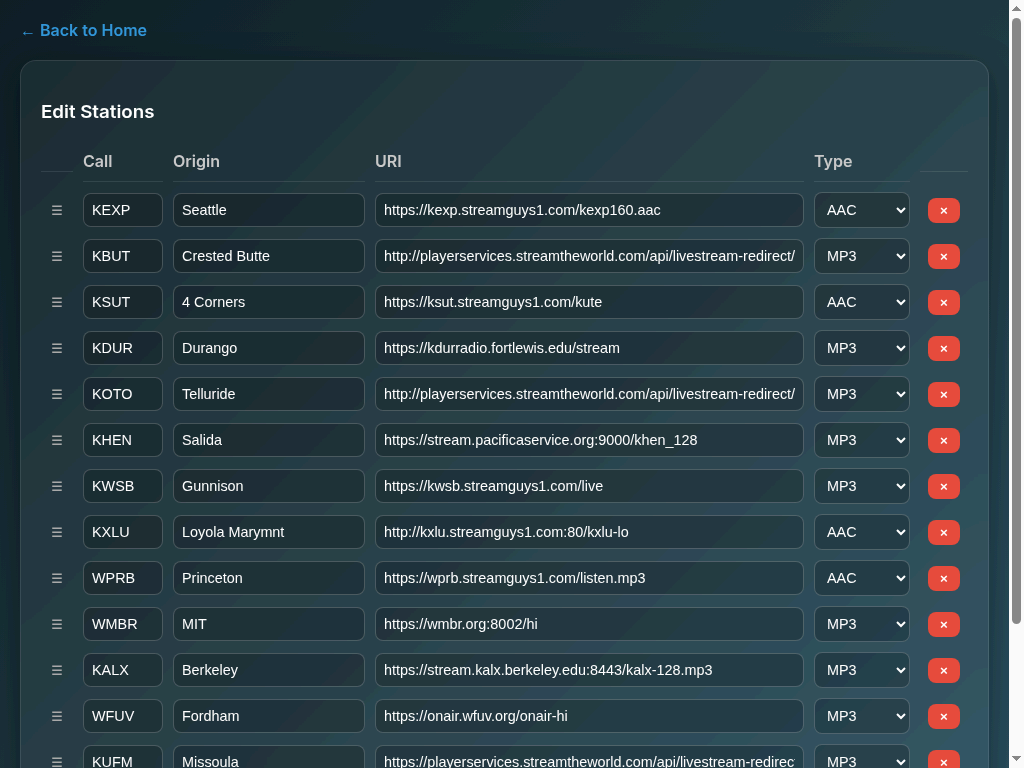
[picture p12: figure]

Figure 3: Station Configuration

Navigate to the station configuration page to manage your radio dial. From this page you can:

- Add New Stations: Enter the Name, Stream URI, and select the appropriate audio codec (MP3, AAC, OGG, or FLAC).
- Edit/Remove Stations: Update existing stream URLs if they change, or delete stations you no longer listen to using the “x” button.
- Reorder: Change the order in which stations appear when you turn the Station knob by dragging the rows up or down.

Changes made on the station configuration page are saved permanently, but the radio may need to be rebooted to apply the new list to the main interface.

### 4. Finding Radio Streams

If you want to add a new station, you will need its direct audio stream URL. Standard website URLs (like npr.org) will not work directly.

The easiest way to find compatible stream URLs is to use fmstream.org.

1. Search for your desired radio station on the site (for example, “KEXP”).
2. Set layout to FULL.

3. Look for the direct streaming links provided in the search results. Next to each URL, you will see the format/codec (e.g., MP3, AAC) and the bitrate (e.g., 128 kbps).
4. Copy the URL that corresponds to the format you want (typically ending in .mp3 or .aac), and paste it into your radio’s Station Configuration page.

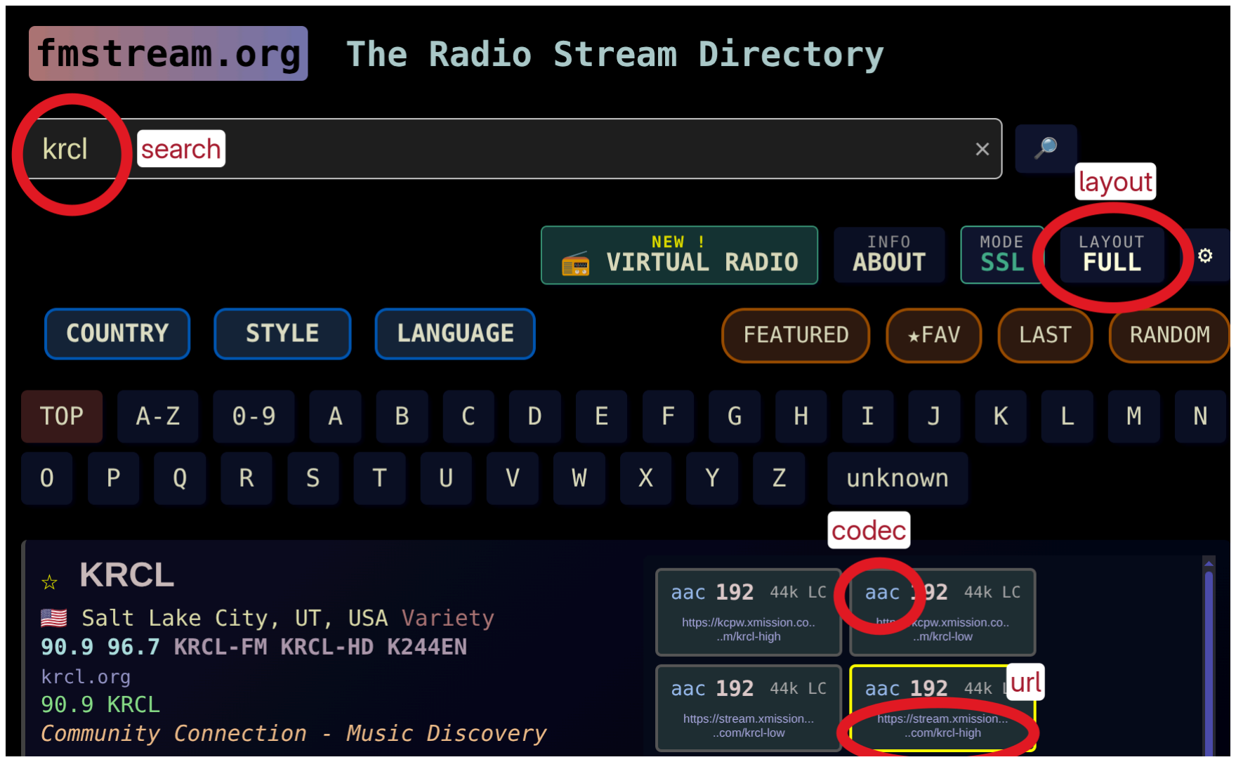
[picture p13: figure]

Figure 4: fmstream KEXP Example

1. In the radio’s configuration, select the exact codec (MP3, AAC, etc.) that was listed next to the URL on the fmstream website.
2. Use origin to help describe the station. You have about 14 characters available on the display.

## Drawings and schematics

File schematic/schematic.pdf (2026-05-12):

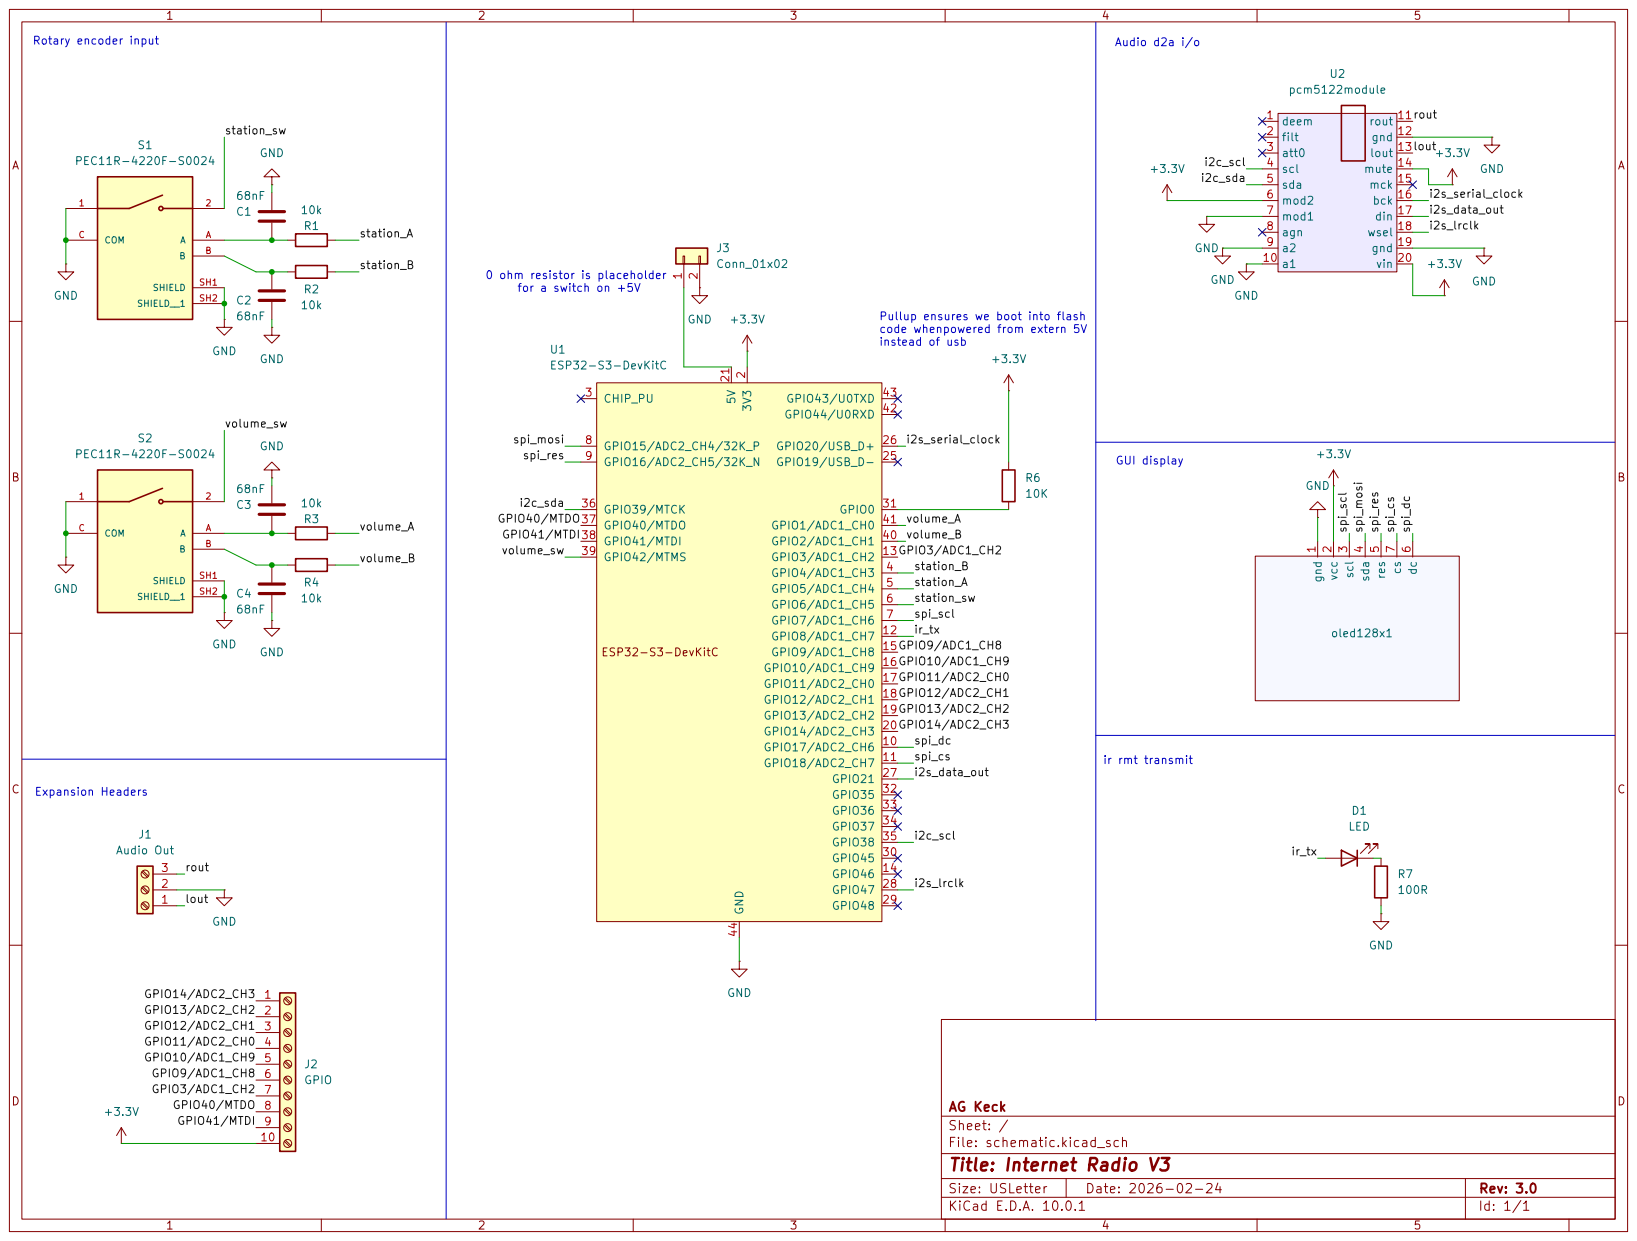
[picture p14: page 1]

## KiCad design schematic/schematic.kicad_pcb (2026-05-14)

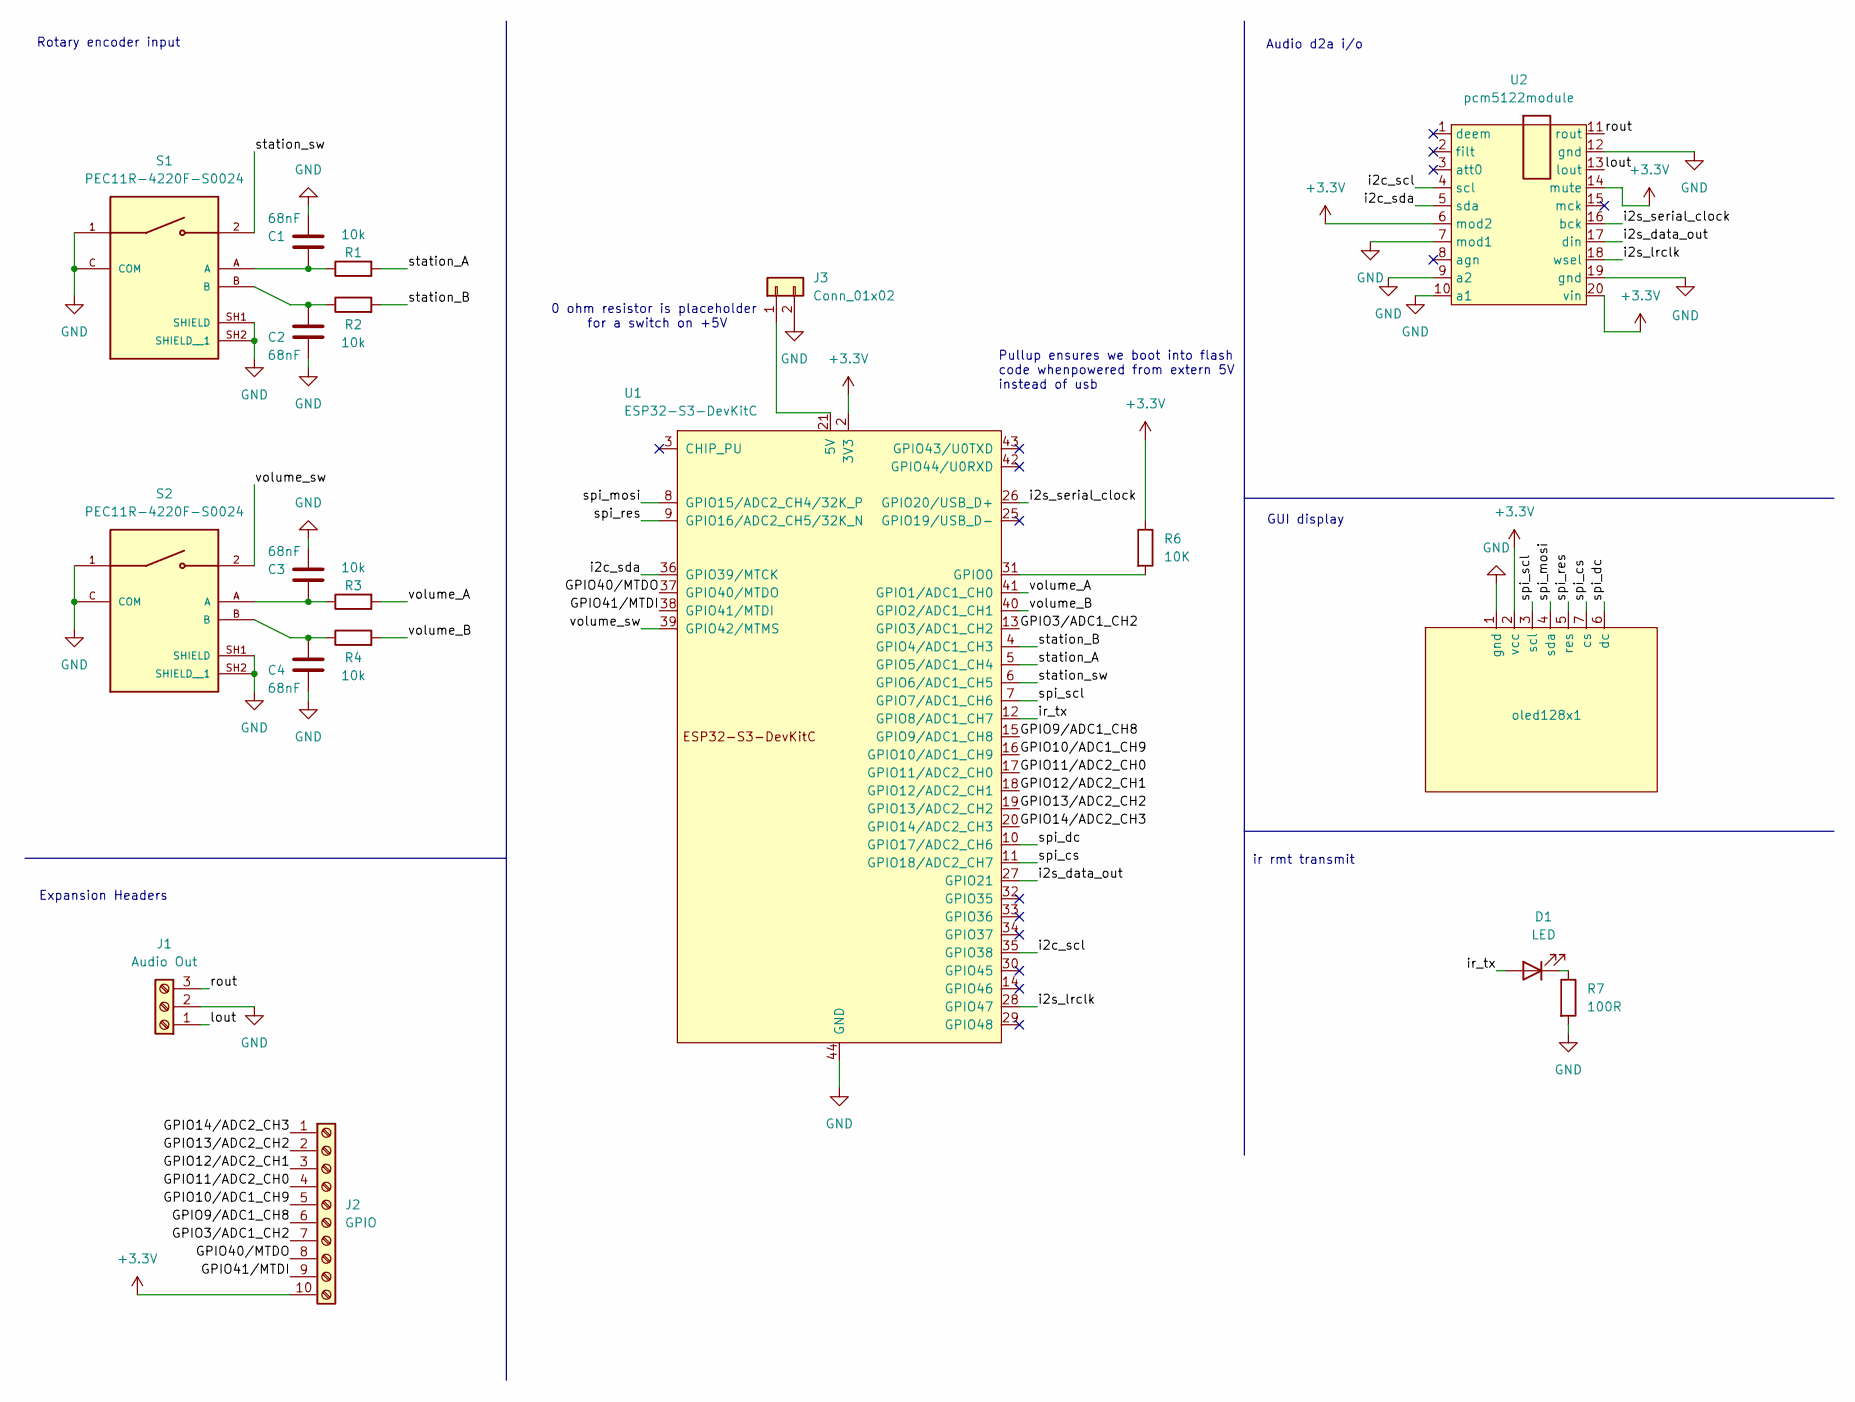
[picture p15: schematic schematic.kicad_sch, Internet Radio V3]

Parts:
C1, C2, C3, C4: 68nF; C_0805_2012Metric_Pad1.18x1.45mm_HandSolder
D1: LED; LED_D3.0mm_IRGrey
J1: Audio Out; TerminalBlock_Xinya_XY308-2.54-3P_1x03_P2.54mm_Horizontal
J2: GPIO; TerminalBlock_Xinya_XY308-2.54-10P_1x10_P2.54mm_Horizontal
J3: Conn_01x02; SolderWire-0.1sqmm_1x02_P3.6mm_D0.4mm_OD1mm
R1, R2, R3, R4: 10k; R_0805_2012Metric_Pad1.20x1.40mm_HandSolder
R6: 10K; R_0805_2012Metric_Pad1.20x1.40mm_HandSolder
R7: 100R; R_0805_2012Metric_Pad1.20x1.40mm_HandSolder
S1, S2: PEC11R-4220F-S0024; XDCR_PEC11R-4220F-S0024; PARTREV 11/23
U1: ESP32-S3-DevKitC
U2: pcm5122module; pcm5122_module
oled128x1: oled128x64_spi

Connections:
+3.3V: J2.10, R6.1, U1.1 (3V3), U1.2 (3V3), U2.6 (mod2), U2.14 (mute), U2.20 (vin), oled128x1.2 (vcc)
/GPIO3/ADC1_CH2: J2.7, U1.13 (GPIO3/ADC1_CH2)
/GPIO9/ADC1_CH8: J2.6, U1.15 (GPIO9/ADC1_CH8)
/GPIO10/ADC1_CH9: J2.5, U1.16 (GPIO10/ADC1_CH9)
/GPIO11/ADC2_CH0: J2.4, U1.17 (GPIO11/ADC2_CH0)
/GPIO12/ADC2_CH1: J2.3, U1.18 (GPIO12/ADC2_CH1)
/GPIO13/ADC2_CH2: J2.2, U1.19 (GPIO13/ADC2_CH2)
/GPIO14/ADC2_CH3: J2.1, U1.20 (GPIO14/ADC2_CH3)
/GPIO40/MTDO: J2.8, U1.37 (GPIO40/MTDO)
/GPIO41/MTDI: J2.9, U1.38 (GPIO41/MTDI)
/i2c_scl: U1.35 (GPIO38), U2.4 (scl)
/i2c_sda: U1.36 (GPIO39/MTCK), U2.5 (sda)
/i2s_data_out: U1.27 (GPIO21), U2.17 (din)
/i2s_lrclk: U1.28 (GPIO47), U2.18 (wsel)
/i2s_serial_clock: U1.26 (GPIO20/USB_D+), U2.16 (bck)
/ir_tx: D1.2 (A), U1.12 (GPIO8/ADC1_CH7)
/lout: J1.1, U2.13 (lout)
/rout: J1.3, U2.11 (rout)
/spi_cs: U1.11 (GPIO18/ADC2_CH7), oled128x1.7 (cs)
/spi_dc: U1.10 (GPIO17/ADC2_CH6), oled128x1.6 (dc)
/spi_mosi: U1.8 (GPIO15/ADC2_CH4/32K_P), oled128x1.4 (sda)
/spi_res: U1.9 (GPIO16/ADC2_CH5/32K_N), oled128x1.5 (res)
/spi_scl: U1.7 (GPIO7/ADC1_CH6), oled128x1.3 (scl)
/station_A: R1.2, U1.5 (GPIO5/ADC1_CH4)
/station_B: R2.2, U1.4 (GPIO4/ADC1_CH3)
/station_sw: S1.2, U1.6 (GPIO6/ADC1_CH5)
/volume_A: R3.2, U1.41 (GPIO1/ADC1_CH0)
/volume_B: R4.2, U1.40 (GPIO2/ADC1_CH1)
/volume_sw: S2.2, U1.39 (GPIO42/MTMS)
GND: C1.2, C2.2, C3.2, C4.2, J1.2, J3.2, R7.2, S1.1, S1.C (COM), S1.SH1 (SHIELD), S1.SH2 (SHIELD__1), S2.1, S2.C (COM), S2.SH1 (SHIELD), S2.SH2 (SHIELD__1), U1.22 (GND), U1.23 (GND), U1.24 (GND), U1.44 (GND), U2.7 (mod1), U2.9 (a2), U2.10 (a1), U2.12 (gnd), U2.19 (gnd), oled128x1.1 (gnd)
unnamed: C1.1, R1.1, S1.A
unnamed: C2.1, R2.1, S1.B
unnamed: C3.1, R3.1, S2.A
unnamed: C4.1, R4.1, S2.B
unnamed: D1.1 (K), R7.1
unnamed: J3.1, U1.21 (5V)
unnamed: R6.2, U1.31 (GPIO0)

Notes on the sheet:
GUI display
0 ohm resistor is placeholder for a switch on +5V
Rotary encoder input
Audio d2a i/o
ir rmt transmit
Pullup ensures we boot into flash code whenpowered from extern 5V instead of usb
Expansion Headers

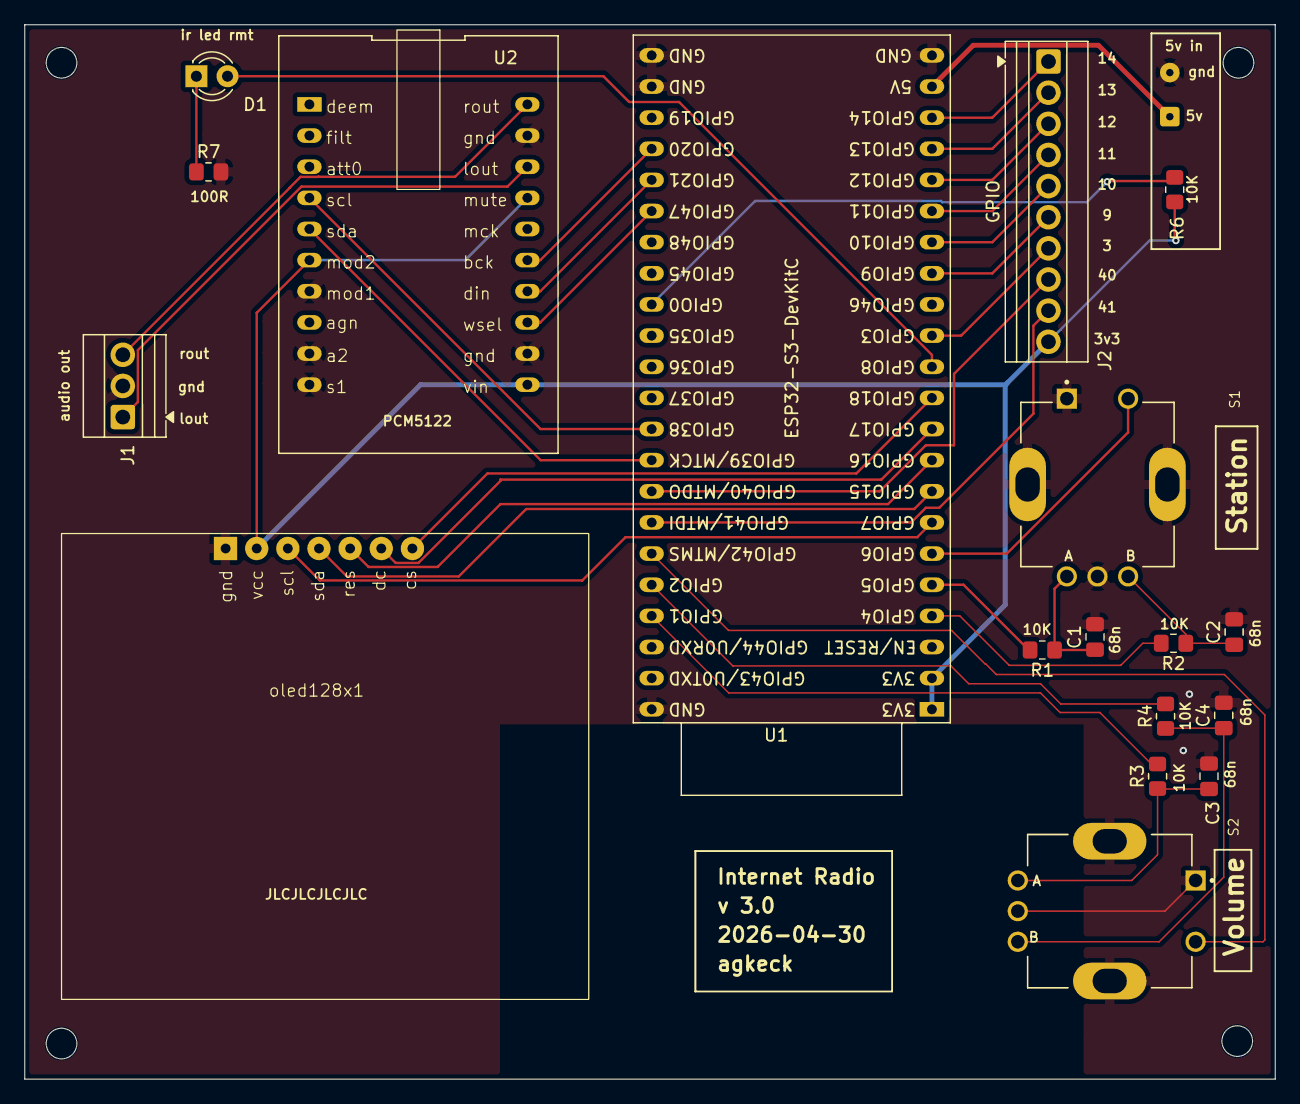
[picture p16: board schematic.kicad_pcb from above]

Board: 2 copper layers, 102.0 x 86.0 mm, 19 parts (0 on the bottom side), 37 nets.

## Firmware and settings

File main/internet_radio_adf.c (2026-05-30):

/* Play internet radio stations

    based on esp-adf code: pipeline_living_stream

   This example code is in the Public Domain (or CC0 licensed, at your option.)

   Unless required by applicable law or agreed to in writing, this
   software is distributed on an "AS IS" BASIS, WITHOUT WARRANTIES OR
   CONDITIONS OF ANY KIND, either express or implied.
*/

// to build from command line:
// source /home/agkeck/.espressif/v5.4.3/esp-idf/export.sh && idf.py build
// but this updates the sdkconfig file for some reason.

#include "audio_common.h"
#include "audio_event_iface.h"
#include "audio_pipeline_manager.h"
#include "board.h"
// #include "driver/gpio.h"
#include "encoders.h"
#include "esp_event.h"
#include "esp_heap_caps.h"
#include "esp_log.h"
#include "esp_netif.h"
#include "esp_peripherals.h"
#include "esp_sleep.h"
#include "esp_wifi.h"
// #include "freertos/FreeRTOS.h"
#include "freertos/event_groups.h"
#include "freertos/task.h"
#include "ir_remote.h"
#include "lvgl_ssd1306_setup.h"
#include "nvs_flash.h"
#include "screens.h"
// #include "sdkconfig.h"
#include "app_config.h"
#include "internet_radio_adf.h"
#include "station_data.h"
#include "web_server.h"
#include "wifi_provisioning/manager.h"
#include "wifi_provisioning/scheme_ble.h"
#include <string.h>

static const char *TAG = "INTERNET_RADIO";

// Volume control
#define INITIAL_VOLUME 60

#include "gpio_assignments.h"

#define BITRATE_UPDATE_INTERVAL_MS 1000

// oled screen with lvgl
extern int station_count; // from station_data.c
static lv_display_t *display;

// global variables for easier access in callbacks
audio_pipeline_components_t audio_pipeline_components = {0};
int current_station = 0;
static bool g_is_sleeping = false;

typedef struct {
  esp_netif_ip_info_t ip_info;
  esp_netif_dns_info_t dns_info;
  uint8_t bssid[6];
  uint8_t channel;
  bool has_state;
} wifi_resume_state_t;

static RTC_DATA_ATTR wifi_resume_state_t g_wifi_resume_state = {0};

#define BITRATE_HISTORY_SIZE 10
static int g_bitrate_history[BITRATE_HISTORY_SIZE] = {0};
static int g_history_index = 0;

audio_board_handle_t board_handle = NULL;
audio_event_iface_handle_t evt = NULL;
esp_periph_set_handle_t periph_set = NULL;
// g_ir_tx_channel is no longer needed globally as it's managed by the ir_remote
// component

volatile int g_bitrate_kbps = 0;
// system monitor logging enable
static bool g_enable_sys_monitor = false;
static int g_consecutive_zero_count = 0;
volatile bool g_is_pipeline_running = false; // Flag to control watchdog
// Button Handles

static EventGroupHandle_t wifi_event_group;
const int WIFI_CONNECTED_BIT = BIT0;

static void save_current_station_to_nvs(int station_index) {
  nvs_handle_t nvs_handle;
  esp_err_t err = nvs_open("storage", NVS_READWRITE, &nvs_handle);
  if (err != ESP_OK) {
    ESP_LOGE(TAG, "Error (%s) opening NVS handle for writing!",
             esp_err_to_name(err));
    return;
  }

  err = nvs_set_i32(nvs_handle, "station_idx", station_index);
  if (err != ESP_OK) {
    ESP_LOGE(TAG, "Error (%s) writing 'station_idx' to NVS!",
             esp_err_to_name(err));
  } else {
    ESP_LOGI(TAG, "Saved current_station = %d to NVS", station_index);
  }

  err = nvs_commit(nvs_handle);
  if (err != ESP_OK) {
    ESP_LOGE(TAG, "Error (%s) committing 'station_idx' to NVS!",
             esp_err_to_name(err));
  }

  nvs_close(nvs_handle);
}

static void save_wifi_state_to_nvs(void) {
  if (!g_wifi_resume_state.has_state)
    return;
  nvs_handle_t nvs_handle;
  esp_err_t err = nvs_open("storage", NVS_READWRITE, &nvs_handle);
  if (err != ESP_OK) {
    ESP_LOGE(TAG, "Error (%s) opening NVS for wifi state save!",
             esp_err_to_name(err));
    return;
  }
  nvs_set_blob(nvs_handle, "wifi_bssid", g_wifi_resume_state.bssid, 6);
  nvs_set_u8(nvs_handle, "wifi_chan", g_wifi_resume_state.channel);
  nvs_set_i32(nvs_handle, "wifi_ip", g_wifi_resume_state.ip_info.ip.addr);
  nvs_set_i32(nvs_handle, "wifi_gw", g_wifi_resume_state.ip_info.gw.addr);
  nvs_set_i32(nvs_handle, "wifi_mask",
              g_wifi_resume_state.ip_info.netmask.addr);
  nvs_set_i32(nvs_handle, "wifi_dns",
              g_wifi_resume_state.dns_info.ip.u_addr.ip4.addr);
  nvs_commit(nvs_handle);
  nvs_close(nvs_handle);
  ESP_LOGI(TAG, "WiFi state saved to NVS (Cold Boot Optimization)");
}

static void load_wifi_state_from_nvs(void) {
  nvs_handle_t nvs_handle;
  esp_err_t err = nvs_open("storage", NVS_READONLY, &nvs_handle);
  if (err != ESP_OK)
    return;
  size_t required_size = 6;
  err = nvs_get_blob(nvs_handle, "wifi_bssid", g_wifi_resume_state.bssid,
                     &required_size);
  if (err != ESP_OK) {
    nvs_close(nvs_handle);
    return;
  }
  nvs_get_u8(nvs_handle, "wifi_chan", &g_wifi_resume_state.channel);
  nvs_get_i32(nvs_handle, "wifi_ip",
              (int32_t *)&g_wifi_resume_state.ip_info.ip.addr);
  nvs_get_i32(nvs_handle, "wifi_gw",
              (int32_t *)&g_wifi_resume_state.ip_info.gw.addr);
  nvs_get_i32(nvs_handle, "wifi_mask",
              (int32_t *)&g_wifi_resume_state.ip_info.netmask.addr);
  nvs_get_i32(nvs_handle, "wifi_dns",
              (int32_t *)&g_wifi_resume_state.dns_info.ip.u_addr.ip4.addr);
  g_wifi_resume_state.dns_info.ip.type = ESP_IPADDR_TYPE_V4;
  g_wifi_resume_state.has_state = true;
  nvs_close(nvs_handle);
  ESP_LOGI(TAG, "WiFi state loaded from NVS (Ready for Fast Connect)");
}

void change_station(int new_station_index) {
  esp_err_t ret;

  if (new_station_index < 0 || new_station_index >= station_count) {
    ESP_LOGE(TAG, "Invalid station index: %d", new_station_index);
    return;
  }

  // Only change if the new station is different from the current one
  if (new_station_index == current_station) {
    ESP_LOGI(TAG, "Station %d is already selected. No change needed.",
             new_station_index);
    return;
  }

  // Mute at start of station change to avoid pops/noise
  if (board_handle && board_handle->audio_hal) {
    audio_hal_set_mute(board_handle->audio_hal, true);
  }

  ESP_LOGI(TAG, "Destroying current pipeline...");
  destroy_audio_pipeline(&audio_pipeline_components);
  vTaskDelay(
      pdMS_TO_TICKS(500)); // Allow network stack and memory manager to settle

  current_station = new_station_index;
  g_is_pipeline_running = false;
  ESP_LOGI(TAG, "Switching to station %d: %s, %s", current_station,
           radio_stations[current_station].call_sign,
           radio_stations[current_station].origin);
  sync_station_encoder_index(); // Sync encoder's internal state
  save_current_station_to_nvs(current_station);
  update_station_name(radio_stations[current_station].call_sign);
  update_station_origin(radio_stations[current_station].origin);

  ret = create_audio_pipeline(&audio_pipeline_components,
                              radio_stations[current_station].codec,
                              radio_stations[current_station].uri);
  if (ret != ESP_OK) {
    ESP_LOGE(
        TAG,
        "Failed to create new audio pipeline for station %s, %s. Error: %d",
        radio_stations[current_station].call_sign,
        radio_stations[current_station].origin, ret);
    // Restore mute state even on failure
    if (board_handle && board_handle->audio_hal) {
      audio_hal_set_mute(board_handle->audio_hal, get_mute_state());
    }
    return;
  }

  ESP_LOGI(TAG, "Starting new audio pipeline");
  reset_throughput_history();
  ret = audio_pipeline_run(audio_pipeline_components.pipeline);

  // Restore mute state after pipeline is started
  if (board_handle && board_handle->audio_hal) {
    audio_hal_set_mute(board_handle->audio_hal, get_mute_state());
  }

  // Link event listener
  if (evt) {
    audio_pipeline_set_listener(audio_pipeline_components.pipeline, evt);
  }

  if (ret != ESP_OK) {
    ESP_LOGE(TAG, "Failed to run new audio pipeline. Error: %d", ret);
    destroy_audio_pipeline(&audio_pipeline_components);
  } else {
    g_is_pipeline_running = true;
  }
}

/* Event handler for catching system events */
static void event_handler(void *arg, esp_event_base_t event_base,
                          int32_t event_id, void *event_data) {
  if (event_base == WIFI_PROV_EVENT) {
    switch (event_id) {
    case WIFI_PROV_START:
      switch_to_provisioning_screen();
      ESP_LOGI(TAG, "Provisioning started");
      break;
    case WIFI_PROV_CRED_RECV: {
      wifi_sta_config_t *wifi_sta_cfg = (wifi_sta_config_t *)event_data;
      ESP_LOGI(TAG,
               "Received Wi-Fi credentials"
               "\n\tSSID: %s\n\tPassword: %s",
               (const char *)wifi_sta_cfg->ssid,
               (const char *)wifi_sta_cfg->password);
      break;
    }
    case WIFI_PROV_CRED_FAIL: {
      wifi_prov_sta_fail_reason_t *reason =
          (wifi_prov_sta_fail_reason_t *)event_data;
      ESP_LOGE(TAG,
               "Provisioning failed!\n\tReason: %s"
               "\n\tPlease reset to factory and retry.",
               (*reason == WIFI_PROV_STA_AUTH_ERROR)
                   ? "Wi-Fi station authentication failed"
                   : "Wi-Fi station not found");
      break;
    }
    case WIFI_PROV_CRED_SUCCESS:
      switch_to_home_screen();
      ESP_LOGI(TAG, "Provisioning successful");
      break;
    case WIFI_PROV_END:
      /* De-initialize manager once provisioning is finished */
      wifi_prov_mgr_deinit();
      break;
    default:
      break;
    }
  } else if (event_base == WIFI_EVENT && event_id == WIFI_EVENT_STA_START) {
    esp_wifi_connect();
  } else if (event_base == WIFI_EVENT && event_id == WIFI_EVENT_STA_CONNECTED) {
    wifi_event_sta_connected_t *event =
        (wifi_event_sta_connected_t *)event_data;
    memcpy(g_wifi_resume_state.bssid, event->bssid, 6);
    g_wifi_resume_state.channel = event->channel;
    ESP_LOGI(
        TAG,
        "Captured WiFi state: BSSID %02x:%02x:%02x:%02x:%02x:%02x, Channel %d",
        g_wifi_resume_state.bssid[0], g_wifi_resume_state.bssid[1],
        g_wifi_resume_state.bssid[2], g_wifi_resume_state.bssid[3],
        g_wifi_resume_state.bssid[4], g_wifi_resume_state.bssid[5],
        g_wifi_resume_state.channel);
  } else if (event_base == IP_EVENT && event_id == IP_EVENT_STA_GOT_IP) {
    ip_event_got_ip_t *event = (ip_event_got_ip_t *)event_data;
    ESP_LOGI(TAG, "Got IP: " IPSTR, IP2STR(&event->ip_info.ip));

    // Cache the IP info for Strategy V3 (DHCP Caching)
    g_wifi_resume_state.ip_info = event->ip_info;

    // Cache DNS info as well
    esp_netif_dns_info_t dns;
    if (esp_netif_get_dns_info(event->esp_netif, ESP_NETIF_DNS_MAIN, &dns) ==
        ESP_OK) {
      ESP_LOGI(TAG, "Main DNS: " IPSTR, IP2STR(&dns.ip.u_addr.ip4));
      g_wifi_resume_state.dns_info = dns;
      g_wifi_resume_state.has_state = true;
      save_wifi_state_to_nvs();
    }
    if (esp_netif_get_dns_info(event->esp_netif, ESP_NETIF_DNS_BACKUP, &dns) ==
        ESP_OK) {
      ESP_LOGI(TAG, "Backup DNS: " IPSTR, IP2STR(&dns.ip.u_addr.ip4));
    }

    xEventGroupSetBits(wifi_event_group, WIFI_CONNECTED_BIT);
  } else if (event_base == WIFI_EVENT &&
             event_id == WIFI_EVENT_STA_DISCONNECTED) {
    wifi_event_sta_disconnected_t *event =
        (wifi_event_sta_disconnected_t *)event_data;
    ESP_LOGI(TAG, "Disconnected. Reason: %d. Connecting to the AP again...",
             event->reason);
    xEventGroupClearBits(wifi_event_group, WIFI_CONNECTED_BIT);

    if (g_is_sleeping) {
      ESP_LOGI(TAG, "Skipping reconnect because g_is_sleeping=true");
      return;
    }

    // Fallback logic for Cached DHCP state failure
    if (g_wifi_resume_state.has_state) {
      ESP_LOGW(TAG,
               "Fast connect failed or connection dropped. Falling back to "
               "full DHCP...");
      g_wifi_resume_state.has_state = false; // Disable resume for next try

      esp_netif_t *netif = esp_netif_get_handle_from_ifkey("WIFI_STA_DEF");
      if (netif) {
        // Clear manual DNS before starting DHCP to avoid interference
        esp_netif_dns_info_t dns = {0};
        esp_netif_set_dns_info(netif, ESP_NETIF_DNS_MAIN, &dns);
        esp_netif_dhcpc_start(netif);
      }

      // Reset WiFi config to normal scan
      wifi_config_t sta_cfg;
      esp_wifi_get_config(WIFI_IF_STA, &sta_cfg);
      sta_cfg.sta.scan_method = WIFI_ALL_CHANNEL_SCAN;
      sta_cfg.sta.bssid_set = false;
      sta_cfg.sta.channel = 0;
      esp_wifi_set_config(WIFI_IF_STA, &sta_cfg);
    }

    esp_wifi_connect();
  }
}
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
void app_main(void) {

  int initial_volume = INITIAL_VOLUME;
  int unmuted_volume = INITIAL_VOLUME;
  bool initial_mute = false;
  esp_log_level_set("*", ESP_LOG_DEBUG);

  esp_sleep_wakeup_cause_t wakeup_reason = esp_sleep_get_wakeup_cause();
  bool waked_by_button = false;
  switch (wakeup_reason) {
  case ESP_SLEEP_WAKEUP_EXT0:
    ESP_LOGI(
        TAG,
        "Wakeup caused by external signal using RTC_IO (EXT0) - Volume Button");
    waked_by_button = true;
    break;
  case ESP_SLEEP_WAKEUP_EXT1:
    ESP_LOGI(TAG, "Wakeup caused by external signal using RTC_CNTL (EXT1)");
    break;
  case ESP_SLEEP_WAKEUP_TIMER:
    ESP_LOGI(TAG, "Wakeup caused by timer");
    break;
  case ESP_SLEEP_WAKEUP_TOUCHPAD:
    ESP_LOGI(TAG, "Wakeup caused by touchpad");
    break;
  case ESP_SLEEP_WAKEUP_ULP:
    ESP_LOGI(TAG, "Wakeup caused by ULP program");
    break;
  case ESP_SLEEP_WAKEUP_GPIO:
    ESP_LOGI(TAG, "Wakeup caused by GPIO (Light Sleep)");
    break;
  default:
    ESP_LOGI(TAG, "Wakeup was not caused by deep sleep or light sleep: %d",
             wakeup_reason);
    break;
  }

  // esp_log_level_set(TAG, ESP_LOG_DEBUG);
  // esp_log_level_set("HTTP_STREAM", ESP_LOG_DEBUG);
  esp_err_t err = nvs_flash_init();
  if (err == ESP_ERR_NVS_NO_FREE_PAGES ||
      err == ESP_ERR_NVS_NEW_VERSION_FOUND) {
    ESP_ERROR_CHECK(nvs_flash_erase());
    err = nvs_flash_init();
  }
  ESP_ERROR_CHECK(err);

  load_app_config();

  load_wifi_state_from_nvs();

  init_station_data();

  nvs_handle_t nvs_handle;
  err = nvs_open("storage", NVS_READWRITE, &nvs_handle);
  if (err != ESP_OK) {
    ESP_LOGE(TAG, "Error (%s) opening NVS handle!", esp_err_to_name(err));
  } else {
    ESP_LOGI(TAG, "Reading current_station from NVS");
    int32_t station_from_nvs = 0; // default to 0
    err = nvs_get_i32(nvs_handle, "station_idx", &station_from_nvs);
    switch (err) {
    case ESP_OK:
      ESP_LOGI(TAG, "Successfully read current_station = %d",
               (int)station_from_nvs);
      if (station_from_nvs >= 0 && station_from_nvs < station_count) {
        current_station = station_from_nvs;
      } else {
        ESP_LOGW(TAG, "Invalid station index %d found in NVS, defaulting to 0",
                 (int)station_from_nvs);
        current_station = 0;
      }
      break;
    case ESP_ERR_NVS_NOT_FOUND:
      ESP_LOGI(TAG, "The value 'station_idx' is not initialized yet!");
      break;
    default:
      ESP_LOGE(TAG, "Error (%s) reading!", esp_err_to_name(err));
    }

    // Read volume from NVS
    ESP_LOGI(TAG, "Reading volume from NVS");
    int32_t volume_from_nvs = INITIAL_VOLUME;
    err = nvs_get_i32(nvs_handle, "volume", &volume_from_nvs);
    switch (err) {
    case ESP_OK:
      ESP_LOGI(TAG, "Successfully read volume = %d", (int)volume_from_nvs);
      if (volume_from_nvs >= 0 && volume_from_nvs <= 100) {
        initial_volume = volume_from_nvs;
      } else {
        ESP_LOGW(TAG, "Invalid volume %d found in NVS, defaulting to %d",
                 (int)volume_from_nvs, INITIAL_VOLUME);
      }
      break;
    case ESP_ERR_NVS_NOT_FOUND:
      ESP_LOGI(TAG, "The value 'volume' is not initialized yet!");
      break;
    default:
      ESP_LOGE(TAG, "Error (%s) reading 'volume'!", esp_err_to_name(err));
    }

    // Default to muted on any reboot/power-on unless woken by button
    initial_mute = true;

    if (waked_by_button) {
      ESP_LOGI(TAG, "Wakeup via button press: Setting state to UNMUTED.");
      initial_mute = false;
    } else {
      ESP_LOGI(TAG, "Cold boot or non-button wakeup: Defaulting to MUTED.");
    }

    // Save the determined mute state to NVS
    err = nvs_set_u8(nvs_handle, "mute_state", initial_mute ? 1 : 0);
    if (err == ESP_OK) {
      nvs_commit(nvs_handle);
    } else {
      ESP_LOGE(TAG, "Error (%s) updating 'mute_state' in NVS!",
               esp_err_to_name(err));
    }

    unmuted_volume = initial_volume;
    // initial_volume is preserved even if initial_mute is true

    nvs_close(nvs_handle);
  }
#if (ESP_IDF_VERSION >= ESP_IDF_VERSION_VAL(4, 1, 0))
  ESP_ERROR_CHECK(esp_netif_init());
#else
  tcpip_adapter_init();
#endif
  display = lvgl_ssd1306_setup();
  screens_init(display);
  update_station_name(radio_stations[current_station].call_sign);
  update_station_origin(radio_stations[current_station].origin);

  // start oled display test task,  remove after debugging
  // xTaskCreate(task_test_ssd1306, "u8g2_task", 4096, NULL, 5, NULL);

  wifi_event_group = xEventGroupCreate();

  ESP_ERROR_CHECK(esp_event_loop_create_default());
  ESP_ERROR_CHECK(esp_event_handler_register(WIFI_PROV_EVENT, ESP_EVENT_ANY_ID,
                                             &event_handler, NULL));
  ESP_ERROR_CHECK(esp_event_handler_register(WIFI_EVENT, ESP_EVENT_ANY_ID,
                                             &event_handler, NULL));
  ESP_ERROR_CHECK(esp_event_handler_register(IP_EVENT, IP_EVENT_STA_GOT_IP,
                                             &event_handler, NULL));

  esp_netif_create_default_wifi_sta();

  wifi_init_config_t cfg = WIFI_INIT_CONFIG_DEFAULT();
  ESP_ERROR_CHECK(esp_wifi_init(&cfg));

  wifi_prov_mgr_config_t config = {
      .scheme = wifi_prov_scheme_ble,
      .scheme_event_handler = WIFI_PROV_SCHEME_BLE_EVENT_HANDLER_FREE_BTDM};

  ESP_ERROR_CHECK(wifi_prov_mgr_init(config));

  // If waking from deep sleep, we want to try Fast Connect immediately
  if (wakeup_reason == ESP_SLEEP_WAKEUP_EXT0 ||
      wakeup_reason == ESP_SLEEP_WAKEUP_TIMER) {
    if (g_wifi_resume_state.has_state) {
      ESP_LOGI(TAG, "Deep sleep wakeup: Cached WiFi state found.");
    }
  }

  // Check for forced provisioning (Volume button held during boot)
  init_encoder_switches();
  if (is_volume_switch_pressed()) {
    ESP_LOGI(TAG, "Volume button held at boot - Forcing Reprovisioning!");
    wifi_prov_mgr_reset_provisioning();
  }

  bool provisioned = false;
  ESP_ERROR_CHECK(wifi_prov_mgr_is_provisioned(&provisioned));
  // provisioned = false; // force provisioning for testing comment this line
  // for production
  uint8_t custom_service_uuid[] = {
      /* LSB <---------------------------------------
       * ---------------------------------------> MSB */
      0xb4, 0xdf, 0x5a, 0x1c, 0x3f, 0x6b, 0xf4, 0xbf,
      0xea, 0x4a, 0x82, 0x03, 0x04, 0x90, 0x1a, 0x02,
  };

  if (!provisioned) {
    ESP_LOGI(TAG, "Starting provisioning");

    char service_name[20];
    get_device_service_name(service_name, sizeof(service_name));

    wifi_prov_scheme_ble_set_service_uuid(custom_service_uuid);
    ESP_ERROR_CHECK(wifi_prov_mgr_start_provisioning(WIFI_PROV_SECURITY_1, NULL,
                                                     service_name, NULL));
    ESP_LOGI(TAG, "Already provisioned, starting Wi-Fi");
  }

  // Start Wi-Fi (non-blocking scan/associate)
  ESP_LOGI(TAG, "Starting Wi-Fi...");
  wifi_init_sta();

  // Initialize hardware ONLY while Wi-Fi connects in the background
  esp_periph_config_t periph_cfg = DEFAULT_ESP_PERIPH_SET_CONFIG();
  periph_set = esp_periph_set_init(&periph_cfg);

  ESP_LOGI(TAG, "Start audio codec chip");
  board_handle = audio_board_init();
  board_handle->audio_hal->audio_codec_ctrl(AUDIO_HAL_CODEC_MODE_BOTH,
                                            AUDIO_HAL_CTRL_START);
  audio_hal_set_volume(board_handle->audio_hal, initial_volume);
  audio_hal_set_mute(board_handle->audio_hal, initial_mute);
  update_volume_slider(initial_volume);

  ESP_LOGI(TAG, "Set up event listener");
  audio_event_iface_cfg_t evt_cfg = AUDIO_EVENT_IFACE_DEFAULT_CFG();
  evt = audio_event_iface_init(&evt_cfg);
  audio_event_iface_set_listener(esp_periph_set_get_event_iface(periph_set),
                                 evt);

  ESP_LOGI(TAG, "Waiting for Wi-Fi connection...");
  xEventGroupWaitBits(wifi_event_group, WIFI_CONNECTED_BIT, false, true,
                      portMAX_DELAY);
  ESP_LOGI(TAG, "Wi-Fi Connected.");

  // Start audio pipeline AFTER WiFi is confirmed connected
  ESP_LOGI(TAG, "Starting audio pipeline...");
  err = create_audio_pipeline(&audio_pipeline_components,
                              radio_stations[current_station].codec,
                              radio_stations[current_station].uri);
  if (err == ESP_OK) {
    reset_throughput_history();
    audio_pipeline_run(audio_pipeline_components.pipeline);
    if (evt) {
      audio_pipeline_set_listener(audio_pipeline_components.pipeline, evt);
    }
    g_is_pipeline_running = true;
  }

  start_web_server();

  xTaskCreate(data_throughput_task, "data_throughput_task", 3 * 1024, NULL, 5,
              NULL);

  //  start encoder pulse counters

  init_encoders(board_handle, initial_volume, initial_mute);
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

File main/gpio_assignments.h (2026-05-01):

#ifndef _GPIO_ASSIGNMENTS_H_
#define _GPIO_ASSIGNMENTS_H_

// ==========================================
// I2C BUS (Audio Codec)
// ==========================================
#define I2C_SDA_GPIO 39
#define I2C_SCL_GPIO 38

// ==========================================
// I2S BUS (PCM5122 Audio Codec)
// ==========================================
// #define I2S_MCK_GPIO              16

#define I2S_BCK_GPIO 20      // note that we can't use internal usb.
#define I2S_DATA_OUT_GPIO 21 // Connects to DIN on PCM5122
#define I2S_WS_LRCK_GPIO 47
#define I2S_DATA_IN_GPIO 4 // Unused by DAC, but defined

// ==========================================
// SPI BUS (SSD1306 Display)
// ==========================================
#define DISPLAY_SPI_SCLK_GPIO 7
#define DISPLAY_SPI_MOSI_GPIO 15
#define DISPLAY_SPI_RST_GPIO 16
#define DISPLAY_SPI_DC_GPIO 17
#define DISPLAY_SPI_CS_GPIO 18

// ==========================================
// ENCODERS (Rotary Push Buttons)
// ==========================================
#define VOLUME_ENCODER_A_GPIO 1
#define VOLUME_ENCODER_B_GPIO 2
#define VOLUME_ENCODER_PRESS_GPIO 42

#define STATION_ENCODER_A_GPIO 5
#define STATION_ENCODER_B_GPIO 4
#define STATION_ENCODER_PRESS_GPIO 6

// ==========================================
// IR REMOTE
// ==========================================
#define IR_TX_GPIO 8

#endif // _GPIO_ASSIGNMENTS_H_

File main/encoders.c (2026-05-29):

/*
 * SPDX-FileCopyrightText: 2010-2022 Espressif Systems (Shanghai) CO LTD
 *
 * SPDX-License-Identifier: CC0-1.0
 */

#include "encoders.h"
//  #include "sdkconfig.h"
#include "driver/gpio.h"
#include "driver/pulse_cnt.h"
#include "esp_log.h"
// #include "freertos/FreeRTOS.h"
#include "freertos/queue.h"
#include "freertos/task.h"

#include "driver/rtc_io.h"

#include "audio_hal.h"
#include "esp_sleep.h"
#include "esp_wifi.h"
#include "nvs_flash.h" // this is needed even though linter suggests otherwise

#include <limits.h>

#include "app_config.h"
#include "board.h"
#include "esp_netif.h"
#include "esp_timer.h"
#include "internet_radio_adf.h"
#include "ir_remote.h"
#include "lvgl_ssd1306_setup.h"
#include "pcm5122_driver.h"
#include "screens.h"
#include "station_data.h"
#include <inttypes.h>

static const char *TAG = "encoders";

// extern audio_board_handle_t board_handle;

extern int station_count;
extern int current_station;
extern audio_pipeline_components_t audio_pipeline_components;

#include "gpio_assignments.h"

// Alias to the consolidated pinout definitions
#define VOLUME_GPIO_A VOLUME_ENCODER_A_GPIO
#define VOLUME_GPIO_B VOLUME_ENCODER_B_GPIO
#define VOLUME_PRESS_GPIO VOLUME_ENCODER_PRESS_GPIO

#define STATION_GPIO_A STATION_ENCODER_A_GPIO
#define STATION_GPIO_B STATION_ENCODER_B_GPIO
#define STATION_PRESS_GPIO STATION_ENCODER_PRESS_GPIO

// polling periods
#define VOLUME_POLLING_PERIOD_MS 100
#define VOLUME_PRESS_POLLING_PERIOD_MS 20

#define STATION_PRESS_POLLING_PERIOD_MS 20

// this pause allows the user to change the station multiple times before the
// change takes effect
#define DELAY_BEFORE_STATION_CHANGE_MS 2000
// timing for long press on station switch to reboot
#define LONG_PRESS_TIME_MS 1500
// time to display IP address on screen
#define IP_SCREEN_DISPLAY_TIME_MS 3000
// reboot message is displayed for this time before rebooting
#define REBOOT_MESSAGE_DISPLAY_TIME_MS 100
// Time window to detect a second click for double-click actions
#define DOUBLE_CLICK_TIMEOUT_MS 300
// Lockout period after wakeup to ignore ghost pulses (500ms)
#define WAKEUP_LOCKOUT_US (500 * 1000)

typedef struct {
  pcnt_unit_handle_t pcnt_unit;
  int speed;
  int value;
  int adjust;
  audio_board_handle_t board_handle;
} limited_pulse_counter_t;

typedef struct {
  pcnt_unit_handle_t pcnt_unit;
  int current_index;
  int num_values;
} cyclic_pulse_counter_t;
static cyclic_pulse_counter_t *g_station_counter_ptr = NULL;

// Mute functionality state
static bool is_muted = false;
static int64_t mute_start_time = 0;
static limited_pulse_counter_t *g_volume_counter_ptr =
    NULL; // Pointer to the volume counter for shared access

static int64_t g_last_wakeup_time = 0;

static void save_volume_to_nvs(int volume) {
  nvs_handle_t nvs_handle;
  esp_err_t err = nvs_open("storage", NVS_READWRITE, &nvs_handle);
  if (err != ESP_OK) {
    ESP_LOGE(TAG, "Error (%s) opening NVS handle for writing volume!",
             esp_err_to_name(err));
    return;
  }

  err = nvs_set_i32(nvs_handle, "volume", volume);
  if (err != ESP_OK) {
    ESP_LOGE(TAG, "Error (%s) writing 'volume' to NVS!", esp_err_to_name(err));
  } else {
    ESP_LOGD(TAG, "Saved volume = %d to NVS", volume);
  }

  err = nvs_commit(nvs_handle);
  if (err != ESP_OK) {
    ESP_LOGE(TAG, "Error (%s) committing 'volume' to NVS!",
             esp_err_to_name(err));
  }

  nvs_close(nvs_handle);
}

static void save_mute_state_to_nvs(bool muted) {
  nvs_handle_t nvs_handle;
  esp_err_t err = nvs_open("storage", NVS_READWRITE, &nvs_handle);
  if (err != ESP_OK) {
    ESP_LOGE(TAG, "Error (%s) opening NVS handle for writing mute state!",
             esp_err_to_name(err));
    return;
  }

  err = nvs_set_u8(nvs_handle, "mute_state", muted ? 1 : 0);
  if (err != ESP_OK) {
    ESP_LOGE(TAG, "Error (%s) writing 'mute_state' to NVS!",
             esp_err_to_name(err));
  } else {
    ESP_LOGD(TAG, "Saved mute_state = %d to NVS", muted);
  }

  err = nvs_commit(nvs_handle);
  if (err != ESP_OK) {
    ESP_LOGE(TAG, "Error (%s) committing 'mute_state' to NVS!",
             esp_err_to_name(err));
  }

  nvs_close(nvs_handle);
}

// update the volume by clamping to range 0-100.  The adjust parameter is used
// to adapt the current pulse count to the clamped volume.  In this way one can
// adjust well below 0 but after ajustment it only take a click to get back
// above 0.
void update_volume_pulse_counter(void *pvParameters) {
  limited_pulse_counter_t *counter = (limited_pulse_counter_t *)pvParameters;
  g_volume_counter_ptr = counter; // Store pointer for global access

  // Restore initial volume to PCNT counter state
  // The counter is at 0, so we need to adjust it to match the initial volume
  int initial_count_offset =
      (counter->value - counter->adjust) * 4 / counter->speed;
  pcnt_unit_clear_count(counter->pcnt_unit);
  // This is a bit of a hack to set the counter. There's no direct 'set_count'
  if (initial_count_offset != 0) {
    // We can't directly set the count, but we can adjust our 'adjust' value
    // so that the next calculation is correct.
    // The formula is: new_volume = count / 4 * speed + adjust
    // We want new_volume to be initial_volume when count is 0.
    counter->adjust = counter->value;
  }

  for (;;) {
    int count;
    ESP_ERROR_CHECK(pcnt_unit_get_count(counter->pcnt_unit, &count));
    int new_volume = count / 4 * counter->speed + counter->adjust;
    if (new_volume < 0) {
      counter->adjust = -count / 4 * counter->speed;
      new_volume = 0;
    } else if (new_volume > 100) {
      counter->adjust = 100 - count / 4 * counter->speed;
      new_volume = 100;
    }
    if (new_volume != counter->value) {
      // Check for lockout period after wakeup
      if (esp_timer_get_time() - g_last_wakeup_time < WAKEUP_LOCKOUT_US) {
        ESP_LOGI(TAG, "Ghost volume pulse ignored (lockout): %d -> %d",
                 counter->value, new_volume);
        counter->value = new_volume;
      } else {
        // If muted and user changes volume, unmute first
        if (is_muted) {
          audio_hal_set_mute(counter->board_handle->audio_hal, false);
          is_muted = false;
          ESP_LOGI(TAG, "Unmuted by volume change to %d", new_volume);
          update_mute_state(false);
          save_mute_state_to_nvs(false);
        }

        counter->value = new_volume;
        audio_hal_set_volume(counter->board_handle->audio_hal, new_volume);
        update_volume_slider(new_volume);
        save_volume_to_nvs(new_volume);
      }
    }

    vTaskDelay(
        pdMS_TO_TICKS(VOLUME_POLLING_PERIOD_MS)); // Poll for volume changes
  }
}
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

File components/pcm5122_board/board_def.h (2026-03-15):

#ifndef _AUDIO_BOARD_DEFINITION_H_
#define _AUDIO_BOARD_DEFINITION_H_

#include "audio_hal.h"

#define FUNC_SDCARD_EN (0)
#define SDCARD_OPEN_FILE_NUM_MAX 5
#define SDCARD_PWR_CTRL -1
#define ESP_SD_PIN_CLK -1
#define ESP_SD_PIN_CMD -1
#define ESP_SD_PIN_D0 -1
#define ESP_SD_PIN_D1 -1
#define ESP_SD_PIN_D2 -1
#define ESP_SD_PIN_D3 -1
#define ESP_SD_PIN_D4 -1
#define ESP_SD_PIN_D5 -1
#define ESP_SD_PIN_D6 -1
#define ESP_SD_PIN_D7 -1
#define ESP_SD_PIN_CD -1
#define ESP_SD_PIN_WP -1

#define FUNC_SYS_LEN_EN (0)
#define GREEN_LED_GPIO -1

#define FUNC_AUDIO_CODEC_EN (0)
#define AUXIN_DETECT_GPIO -1
#define HEADPHONE_DETECT -1
#define PA_ENABLE_GPIO -1
#define CODEC_ADC_I2S_PORT ((i2s_port_t)0)
#define CODEC_ADC_BITS_PER_SAMPLE ((i2s_data_bit_width_t)16)
#define CODEC_ADC_SAMPLE_RATE (48000)
#define RECORD_HARDWARE_AEC (false)
#define BOARD_PA_GAIN (10)

#include "app_config.h"

#define AUDIO_ADC_INPUT_CH_FORMAT "N"

extern audio_hal_func_t MY_AUDIO_CODEC_PCM5122_DEFAULT_HANDLE;

#define AUDIO_CODEC_DEFAULT_CONFIG()                                           \
  {                                                                            \
      .adc_input = AUDIO_HAL_ADC_INPUT_LINE1,                                  \
      .dac_output = AUDIO_HAL_DAC_OUTPUT_ALL,                                  \
      .codec_mode = AUDIO_HAL_CODEC_MODE_DECODE,                               \
      .i2s_iface =                                                             \
          {                                                                    \
              .mode = AUDIO_HAL_MODE_SLAVE,                                    \
              .fmt = AUDIO_HAL_I2S_NORMAL,                                     \
              .samples = AUDIO_HAL_48K_SAMPLES,                                \
              .bits = AUDIO_HAL_BIT_LENGTH_16BITS,                             \
          },                                                                   \
  };

#define FUNC_BUTTON_EN (1)
#define INPUT_KEY_NUM 6
#define BUTTON_REC_ID -1
#define BUTTON_MODE_ID -1
#define BUTTON_SET_ID -1
#define BUTTON_PLAY_ID -1
#define BUTTON_VOLUP_ID -1
#define BUTTON_VOLDOWN_ID -1

#define INPUT_KEY_DEFAULT_INFO()                                               \
  {                                                                            \
  }

#endif

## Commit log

2026-02-20 add link to audio board docs to readme
2026-02-24 Add pullup resistor to gpio 0. This ensures that strapping pin gpio 0 is high when booting from external 5V supply. In breadboard testing this did not affect booting from USB jack.
    [schematic.kicad_sch]
2026-02-25 Change audio board from es8388 to pcm5122. Keep gpio assignments the same but they should be remapped before pcb layout. Works, but is much too loud
2026-02-25 Added stubs to allow all esp adf drivers to compile. My driver doesn't use these functions.
    [board_pins_config.c]
2026-02-27 Move from es8388 board to pcm5122 board. Interestingly, The adafruit driver (thanks to Limor Fried) was written with assistance from Claude code. I used gemini to read that code and adapt it to esp a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
2026-02-27 Ensure that the volume is preserved in NVS when the radio is muted and a reboot occurs.
    [internet_radio_adf.c]
2026-02-27 feat: Mute audio during station changes to prevent pops and update the mute indicator from 'X' to 'M'.
    [encoders.c, internet_radio_adf.c]
2026-03-01 feat: Implement LVGL monochrome rendering for SSD1306, add WiFi power management functions, and downgrade IDF to 5.4.3. Actually, vscode has been using 5.4.3 but sdkconfig did not reflect that.
2026-03-01 feat: Introduce a global throughput history and reset it when the audio pipeline starts or reconnects. This gives correct readings when a stream is just starting.
    [audio_pipeline_manager.c, internet_radio_adf.c]
2026-03-01 Fixed problem with reawakened wifi connection losing DNS connectivity.
    [internet_radio_adf.c]
2026-03-02 Added 500ms delay upon wake before encoders are make active. Spurious signals on encoder lines were counted at wake time, this should be stopped now. Updated KOTO url.
2026-03-04 turn off task watchdog timer while in light sleep to avoid triggers.
    [audio_pipeline_manager.c]
2026-03-04 moved wake up time to the very start of wakeup to mute spurious encoder events on wakeup.
2026-03-04 feat: Implement robust light-to-deep sleep transition with timer-based light sleep and EXT0 deep sleep wakeup, and update project version.
2026-03-05 created power saving strategy with values none, light sleep, light+deep sleep to control behavior. pulled delays out as variables for eventual configuration via settings page.
2026-03-08 Add guards to prevent the throughput wdt from advancing during sleep. We destroy the pipeline prior to sleep causing the throughput to drop to zero. If the esp_light_sleep_start() function blocks wai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
    [audio_pipeline_manager.c, internet_radio_adf.c]
2026-03-08 set light sleep delay to 10 seconds to facilitate testing. Don't forget to replace this with 20 minutes for production.
    [encoders.c]
2026-03-12 Moved wifi reconnect data to RTC safe memory and try that data up reawakeing from deep sleep. This caches IP address and DNS settings. If it work waking from deep sleep should drop below 11 seconds. 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
    [internet_radio_adf.c]
2026-03-13 Chnged the label on display from KBPS to kb/s. Straight lower case doesn't work since the descender on the 'p' is cut off.
2026-03-15 docs: Add Version 3 software highlights, PCM5122 DAC integration details, and a power management table to the README.
2026-03-15 feat: Implement web-based configuration for audio settings and power management, and clean up unused SDK configurations. Configuration is now stored in NVS
2026-03-31 Update schematic with note about pullup on GPIO0 for booting from external 5V, bypassing usb.
    [schematic.kicad_sch]
2026-04-19 refactor: update I2S bus pins and reformat GPIO definitions for consistency. Note that gpio48 is dedicated to the onboard rgb led and so cannot be used for signal.
2026-04-19 docs: add GPIO constraints reference and clarify internal USB pin conflicts in assignments header
2026-04-19 chore: update GPIO pin assignments for I2C bus for better layout. temporarily moved station encoder A to make room.
2026-04-19 Added cad files for laying out the pcb. the .x_t file is proprietary but I was able to conver to .stp for import into kikad using online converter at https://3dencoder.com/XT-to-stp
2026-04-23 moved station encoder and ir_tx gpios.
2026-04-23 Moved spi gpio pin assignments.
2026-04-23 update gpio assignments on schematic.
    [schematic.kicad_sch]
2026-04-26 moved ir rmt gpio to (perhaps) improve trace routing.
2026-04-28 Assigned footprints and created custom footprints in prepartion for pcb layout.
    [schematic.kicad_pcb, schematic.kicad_sch]
2026-04-29 Change current limiting resistor to 100R from 33R. Lower power seems to work fine for the ir remote.
    [schematic.kicad_sch]
2026-04-30 Reordered station encoder gpio assignments for cleaner routing.
2026-04-30 Gitignore transient files involved with schematic and pcb.
2026-04-30 Design PCB.
    [schematic.kicad_pcb, schematic.kicad_sch]
2026-05-01 Added minimal operating instructions to back silkscreen.
    [schematic.kicad_pcb]
2026-05-01 Reassigned volume encoder pins in order to reroute outside of the esp32 antenna. Also added a keep out zone on both top and bottom around the antenna.
    [schematic.kicad_pcb, schematic.kicad_sch]
2026-05-01 Expanded keep out zone around antenna. Recommendations suggest 15mm. I am able to keep the ground plane out but there are still three pads and traces in the keep out region. These are related to the 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
    [schematic.kicad_pcb]
2026-05-01 Added rounting for common on volume encoder. The part of the volume encoder in the keep out region was the rotary encoder. Without the ground plane the common was not connected so I added a trace to 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
    [schematic.kicad_pcb]
2026-05-02 Fixed two islands in the front ground plane by adding vias.
    [schematic.kicad_pcb]
2026-05-02 Generated gerbers and bom.
    [schematic.kicad_pcb, schematic_bom.csv]
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2026-05-12 moved to kicad 10
    [schematic.kicad_sch]
2026-05-14 update pcb to kicad 10
    [schematic.kicad_pcb]
2026-05-14 update gitignore to ignore history and lock files associated with kicad
2026-05-14 chore: update .gitignore to exclude additional KiCad schematic artifacts and directories
2026-05-16 Change the default digital attenuation to -3db. This works well with the tivoli audio device.
2026-05-16 moved wake up functions to station press. volume switch is on gpio 42 which is not RTC enabled. While not ideal we now press the volume to mute/sleep and station to unmute/wake basically volume for o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
2026-05-17 update readme with images of build and schematic.
2026-05-17 increased the polling rate on the volume button to catch very quick clicks. With the new build very quick clicks are easy so this accomodates the new build.
2026-05-18 fixed a problem where wakup from deep sleep did not send audio on ir remote signal.
    [audio_pipeline_manager.c, encoders.c, internet_radio_adf.c]
2026-05-18 feat: trigger IR remote audio power-on when unmuting the device
2026-05-18 feat: add support for DUBAS_RADIO IR protocol and replace boolean toggle with protocol configuration
    [app_config.h, audio_pipeline_manager.c, encoders.c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]
2026-05-19 Send ir rmt command to turn on radio after the first frame of audio is decoded. This ensures that the high current demands of establishing a connection are mostly done so that the ir led can get full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
2026-05-19 fix spelling in schematic.
    [schematic.kicad_sch]
2026-05-20 Corrected KRCL stream url.
    [station_data.c]
2026-05-21 New ir behavior: audio on when first frame of audio is decoded, regardless of mute state. Audio off when going into light sleep. There is a possibility that upon rebooting from power outage the ir re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
    [audio_pipeline_manager.c, encoders.c]
2026-05-22 Add error logging to turn_audio_on() to diagnose occasional ir rmt misses.
    [ir_remote.c]
